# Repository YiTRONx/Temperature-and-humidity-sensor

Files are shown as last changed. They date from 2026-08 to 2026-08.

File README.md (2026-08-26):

# 温湿度传感器 Temperature-and-humidity-sensor
这是我的本科毕业设计，基于微信小程序的温湿度监测系统。主体基于esp32-s3 supermini，通过蓝牙或wifi连接微信小程序，实现温湿度的远程查询、阈值报警、历史数据查看等功能。
> Temperature and Humidity Monitoring System Based on WeChat Mini Program







基于 **ESP32-S3 + AHT10** 的物联网温湿度监测系统，以**微信小程序**作为上位机，通过**蓝牙**完成设备配网与本地参数配置，通过 **WiFi + MQTT** 实现远程数据上报与实时监测，配合 **Node-RED + Mosquitto** 服务器完成数据持久化、历史查询与微信报警推送。

低成本、高集成、易部署的远程温湿度监测解决方案，适用于农业大棚、仓储库房、机房、智能家居等场景。

**部分关于项目的图片可以查看仓库中的“基于微信小程序的温湿度监测系统.pdf”文件**

---

## 项目简介 / Introduction

传统温湿度监测方式存在布线复杂、交互性差、专用客户端适配繁琐等问题，难以满足远程智能监测需求。本项目打造一套完整闭环的物联网监测系统，采用**硬件采集层 → 无线通信层 → 服务器层 → 小程序应用层**的四层架构，覆盖"采集 — 传输 — 存储 — 交互"全链路：

- **硬件采集层**：以 ESP32-S3 为主控，搭配 AHT10 高精度温湿度传感器与 OLED 显示屏，完成数据采集与本地可视化；
- **无线通信层**：蓝牙负责近场配置（配网、参数下发），WiFi 负责远程数据传输（MQTT 上报）；
- **服务器层**：部署 Mosquitto 消息代理与 Node-RED 数据处理流，实现数据持久化、历史查询接口与微信通知推送，并通过内网穿透提供公网访问；
- **应用层**：微信小程序提供设备管理、实时监测、参数设置、历史数据查询等可视化交互。

## 功能特性 / Features

- 📊 **实时监测**：ESP32 双核并行采集，数据经 MQTT 实时上报，小程序同步展示温湿度数值与动态曲线
- 📡 **双模通信**：蓝牙 BLE（近场配置与数据传输）+ WiFi（远程上报与服务器通信）
- 🔧 **蓝牙配网**：无需将 WiFi 账号密码写死在固件中，小程序内直接下发 SSID / 密码完成入网
- 🚨 **阈值报警**：温度、湿度上下限均可配置，超限即时上报，服务器向用户微信推送报警通知
- 🗂️ **历史数据**：服务端按日持久化为 CSV 文件，小程序按日期查询并绘制历史曲线
- 🔗 **多设备管理**：蓝牙扫描绑定、多设备列表、断线自动重连
- 🖥️ **本地可视化**：0.96 寸 OLED 实时显示温湿度、通信状态与阈值信息
- 💾 **参数持久化**：全部配置写入 Flash（Preferences），掉电复位不丢失
- 🔋 **低功耗设计**：联网成功后自动关闭蓝牙，触摸唤醒 + 定时熄屏

## 系统架构 / Architecture

```
┌────────────────────────────────────────────────────────────────┐
│                    微信小程序（应用层）                             │
│   设备总览 · 实时监测 · 参数设置 · 历史数据 · 个人中心                   │
└───────────┬──────────────────────────────────┬──────────────────┘
            │ MQTT over WebSocket              │ HTTP
            │ 实时数据订阅                        │ 历史 CSV 查询
┌───────────▼──────────────────────────────────▼──────────────────┐
│           服务器层（Mosquitto + Node-RED）                         │
│   数据接收转发 · CSV 持久化 · HTTP 查询接口 · 微信报警通知              │
└───────────┬─────────────────────────────────────────────────────┘
            │ MQTT over TCP
┌───────────▼─────────────────────────────────────────────────────┐
│        无线通信层（ESP32 双模）                                     │
│   蓝牙 BLE（近场配置 / 指令下发）   WiFi（远程数据上传）                 │
└───────────┬─────────────────────────────────────────────────────┘
            │ I2C
┌───────────▼─────────────────────────────────────────────────────┐
│        硬件采集层（ESP32-S3 + AHT10 + OLED + 触摸开关）              │
└─────────────────────────────────────────────────────────────────┘
```

```mermaid
graph LR
    A[AHT10 温湿度传感器] -->|I2C| B[ESP32-S3]
    C[SSD1315 OLED] -->|I2C| B
    D[TTP223 触摸开关] -->|GPIO| B
    B -->|BLE| E[微信小程序]
    B -->|WiFi / MQTT| F[Mosquitto 消息代理]
    F --> G[Node-RED 数据处理流]
    G --> H[CSV 历史数据]
    G --> I[微信报警通知]
    E -->|MQTT / HTTP| F
```

核心数据链路：硬件采集温湿度 → WiFi / MQTT 上传至服务器存储 → 小程序通过 MQTT 获取实时数据、通过 HTTP 查询历史数据 → 小程序指令经蓝牙下发至硬件，实现双向交互。

## 技术栈 / Tech Stack

| 层级 | 技术 |
| --- | --- |
| 硬件 | ESP32-S3 Supermini、AHT10、SSD1315 OLED、TTP223 触摸开关 |
| 固件 | Arduino C、ESP32 双核任务调度、BLE、PubSubClient、Preferences |
| 服务器 | Mosquitto（MQTT Broker）、Node-RED、CSV、内网穿透 |
| 客户端 | 微信小程序原生开发（WebSocket 手写 MQTT 3.1.1 报文、Canvas 图表） |

## 目录结构 / Project Structure

```
Temperature-and-humidity-sensor
├── main_BLE_WiFi_MQTT_DualCore_NoEEPROM_Set.ino   # ESP32-S3 固件（Arduino）
└── wxamp_main/                                    # 微信小程序
    ├── app.js / app.json / app.wxss                # 全局逻辑、页面与样式配置
    ├── pages/
    │   ├── equipment/                              # 设备总览（蓝牙扫描 / 连接）
    │   ├── detailed/                               # 实时监测详情（数值 + 动态曲线）
    │   ├── detailed/detaileddaily/                 # 历史数据查询
    │   ├── setpage/                                # 参数设置入口
    │   │   ├── equwifi/                            # WiFi 配网
    │   │   ├── equalarm/                           # 温湿度告警阈值
    │   │   ├── equnickname/                        # 设备昵称
    │   │   ├── equdetailed/                        # 设备详情
    │   │   ├── equadd/                             # 添加设备
    │   │   └── otherset/                           # 其他设置
    │   ├── my/                                     # 个人中心（含通知、通用、帮助）
    │   ├── login/                                  # 用户登录
    │   └── canvasfortime/                          # 图表绘制
    ├── icons/                                      # 界面图标资源
    ├── utils/                                      # 工具函数（MQTT 封装、格式化等）
    └── date-csv/                                   # 历史数据文件示例
```

## 硬件设计 / Hardware Design

系统以**高集成度、低功耗、易调试**为选型原则，采用模块化连接设计，通过 SH1.0 接口实现各外设与主控的可靠对接，并由主控板提供 3.3V 供电。

### 硬件清单

| 模块 | 型号 | 说明 |
| --- | --- | --- |
| 主控 | ESP32-S3 Supermini | WiFi + BLE 双模、双核 240MHz，Type-C 供电与程序烧录 |
| 温湿度传感器 | AHT10 | I2C 通信，温度 -40~85℃（±0.3℃），湿度 0~100%RH（±2%RH），宽电压 1.8~6.0V |
| 显示屏 | SSD1315 0.96" OLED | I2C 128×64，本地数据与状态可视化 |
| 触摸开关 | TTP223 | 低电平触发屏幕唤醒，降低功耗 |
| 外壳 | 3D 打印（上下卡扣式） | 一体化成品，提升防护与质感 |
| PCB | 嘉立创 EDA 定制 | 紧凑化、模块化、易装配，SH1.0 贴片接口 |

### 引脚连接

| 外设 | 引脚 / 地址 | 说明 |
| --- | --- | --- |
| I2C SDA | GPIO8 | AHT10 与 OLED 共用 |
| I2C SCL | GPIO9 | AHT10 与 OLED 共用 |
| AHT10 | I2C 地址 `0x38` | 温湿度采集 |
| OLED | I2C 地址 `0x3C` | 本地显示 |
| 触摸开关 | GPIO13 | 屏幕唤醒触发 |

### 固件默认配置

| 配置项 | 默认值 |
| --- | --- |
| 设备广播名 | `ESP32-TH-V2` |
| 默认设备昵称 | `温湿度传感器V2.1` |
| 温度告警阈值 | 0 ~ 30℃ |
| 湿度告警阈值 | 0 ~ 80%RH |
| 采样 / 上报间隔 | 2000 ms |
| 熄屏时间 | 0（常亮） |
| NTP 服务器 | `ntp.aliyun.com`（UTC+8） |

## 通信协议 / Communication Protocols

### MQTT 主题

| 主题 | 方向 | 说明 |
| --- | --- | --- |
| `home/sensor/th` | 设备 → 服务器 | 实时温湿度数据上报 |
| `home/alarm/th` | 设备 → 服务器 | 阈值报警消息 |
| `device/online` | 设备 → 服务器 | 设备上线状态 |

实时数据上报格式（JSON）：

```json
{
  "time": "2026-03-15 10:00:00",
  "UUID": "<设备唯一标识>",
  "Nickname": "客厅传感器",
  "Location": "客厅",
  "temp": 25.3,
  "humi": 45.6
}
```

小程序端通过 WebSocket 连接 MQTT Broker（如 `ws://<服务器地址>:<端口>/mqtt`），手写 MQTT 3.1.1 报文完成连接与主题订阅，无需第三方库，并支持断线退避重连。

### 蓝牙 BLE

- **服务 UUID / 特征 UUID**：定义于固件头部（`SERVICE_UUID` / `CHARACTERISTIC_UUID`），小程序按服务 UUID 前缀匹配
- **特征属性**：READ + WRITE + NOTIFY + INDICATE，MTU 512
- **实时数据广播格式**：`温度,湿度`（如 `25.3,45.6`）

### 蓝牙指令集

| 指令 | 功能 | 回复 |
| --- | --- | --- |
| `WIFI:<ssid>,<password>` | 下发 WiFi 配网信息 | `WIFI_OK` / `WIFI_FORMAT_ERR` |
| `TEMP:<lower>,<upper>` | 设置温度告警阈值 | `TEMP_OK:<lower>,<upper>` |
| `HUM:<lower>,<upper>` | 设置湿度告警阈值 | `HUM_OK:<lower>,<upper>` |
| `NICK:<名称>` | 设置设备昵称（UTF-8） | `NICK_OK` / `NICK_FAIL` |
| `LOC:<位置>` | 设置安装位置 | `LOC_OK` / `LOC_FAIL` |
| `MQTT:<server>,<port>` | 设置 MQTT 服务器 | `MQTT_OK` / `MQTT_FAIL` |
| `REFRESH:<ms>` | 设置采样 / 上报间隔（500~30000 ms） | `REFRESH_OK` / `REFRESH_FAIL` |
| `SCREEN:<ms>` | 设置熄屏时间（0=常亮） | `SCREEN_OK` |
| `GET_CONFIG` | 读取全部配置 | `TEMP|HUM|NICK|LOC|MQTT|REFRESH|SCREEN` |
| `CLEAR` | 清除全部配置并恢复默认 | `CLEAR_OK` |

### HTTP 历史数据接口

```
GET /<设备UUID>/<YYYY-MM-DD>.csv
```

服务端返回按 `日期 时间 温度 湿度` 排列的 CSV 文件，小程序本地解析并绘制历史曲线。

## 快速开始 / Quick Start

### 1. 烧录固件（ESP32-S3）

1. 安装 Arduino IDE（或 PlatformIO），并安装 ESP32 开发板支持包；
2. 安装依赖库：`U8g2lib`、ESP32 BLE 库、`PubSubClient`、`Preferences`；
3. 按需修改固件头部配置：MQTT 服务器地址与端口、NTP 服务器（默认 `ntp.aliyun.com`，时区 UTC+8）等，也可通过小程序蓝牙指令动态下发；
4. 使用 Type-C 连接开发板，选择对应串口编译烧录。

### 2. 搭建服务器（远程监测依赖）

1. 部署 **Mosquitto** MQTT 消息代理，开放 TCP 端口（设备上报）与 WebSocket 端口（小程序订阅）；
2. 导入 **Node-RED** 数据处理流，包含四条核心流程：
   - 订阅 MQTT 设备主题 → 按 `<UUID>/<日期>.csv` 规则持久化存储；
   - HTTP GET 查询接口 → 读取并返回历史 CSV 文件；
   - 用户登录 → 获取并存储微信 OpenID；
   - 报警主题 → 触发微信通知推送；
3. 使用内网穿透工具（如 cpolar）将 MQTT、Node-RED 等端口映射到公网，实现设备与小程序跨网络稳定通信。

### 3. 运行微信小程序

1. 使用微信开发者工具导入 `wxamp_main` 目录；
2. 填入小程序 AppID，并配置以下服务器地址：
   - MQTT over WebSocket 地址（如 `ws://<服务器地址>:<端口>/mqtt`）；
   - HTTP 历史数据接口地址；
3. 编译预览。蓝牙扫描、配网等功能需在真机上测试。

## 使用指南 / Usage Guide

1. **添加设备**：设备总览页点击"+"，扫描并绑定附近的温湿度传感器；
2. **蓝牙配网**：进入设置页 WiFi 选项，下发 WiFi 名称与密码，设备自动联网并连接 MQTT 服务器；
3. **实时监测**：详情页以数值与动态曲线双形式展示温湿度，更新频率与设备采样周期一致；
4. **参数配置**：通过蓝牙可调整告警阈值、设备昵称、安装位置、采样间隔、熄屏时间等；
5. **历史查询**：历史数据页选择日期，小程序请求 CSV 并绘制当日温湿度曲线；
6. **阈值报警**：数据越限后设备上报报警消息，服务器向用户微信推送通知；
7. **登录授权**：个人中心支持头像、昵称设置与微信通知授权。

## 技术亮点 / Highlights

- **双核任务调度**：核心 1 独立完成 NTP 时间同步与 MQTT 连接，避免网络阻塞核心 0 的采集与显示流程；
- **原生 WebSocket 实现 MQTT**：小程序端手写 MQTT 3.1.1 报文（CONNECT / SUBSCRIBE / PUBLISH 解析），零第三方依赖，支持断线退避重连；
- **动态配网**：WiFi 凭证经蓝牙下发，账号密码不再写死在固件中；
- **参数持久化**：基于 Preferences（NVS Flash）替代 EEPROM，断电复位后配置不丢失；
- **省电策略**：WiFi 与服务器连接成功后自动关闭蓝牙；触摸唤醒 + 定时熄屏；
- **成品化落地**：定制 PCB + 3D 打印外壳，完成从模块化调试到一体化成品的全流程。

## 测试与验证 / Testing

- **功能测试**：蓝牙扫描 / 绑定、WiFi 配网、MQTT 实时数据、参数下发、历史查询、阈值报警推送均通过验证；
- **精度验证**：小程序显示数据与硬件 OLED 显示完全一致，采集误差满足传感器标称精度；
- **稳定性测试**：长时间运行无断连、死机、数据错乱，满足农业、仓储、家居等多场景监测需求。

## 应用场景 / Use Cases

- 🌱 农业大棚温湿度监测
- 📦 仓储库房环境监控
- 🖥️ 机房 / 设备间环境保障
- 🏠 智能家居环境感知
- 📷 摄影器材、贵重物品防潮监测

## 开源许可 / License

本项目仅供学习、毕业设计参考使用。

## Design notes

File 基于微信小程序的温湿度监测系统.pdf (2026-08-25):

目录

CONTENTS

## 项目设计说明

Project Design Description

## 硬件设计与服务器部署

## 测试与总结

## 微信小程序设计

WeChat Mini Program Design

Hardware Design and Server Deployment

Testing and summary

1
2
3

4

# 项目设计说明

Project Design Description

1

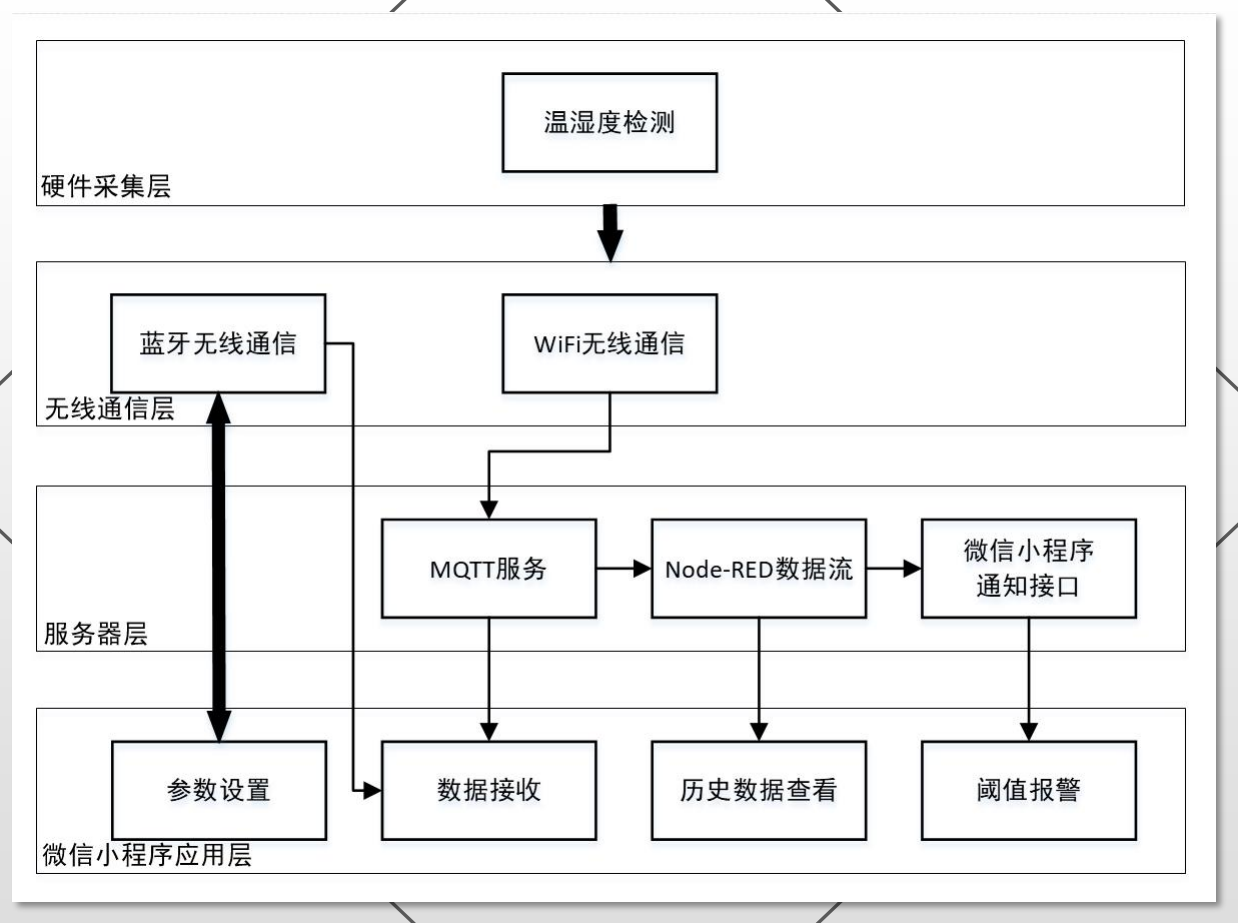
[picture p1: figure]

# 项目设计说明

Project Design Description

本项目设计基于微信小程序的温湿度监测
系统，采用硬件采集、无线通信、服务器、小
程序应用四层物联网架构。系统以ESP32-S3为
主控，搭配AHT10传感器与OLED屏，通过定制
PCB和3D打印外壳实现成品化，双核调度实现
稳定运行。

采用蓝牙、WiFi双通信模式，结合MQTT协
议与服务器，完成远程数据传输和存储、历史
查询及微信告警推送。微信小程序实现蓝牙配
网、实时监测、参数设置与数据可视化。系统
功能完整、操作便捷，适用于多场景智能监测。

WeChat Mini Program Design

# 微信小程序设计

2

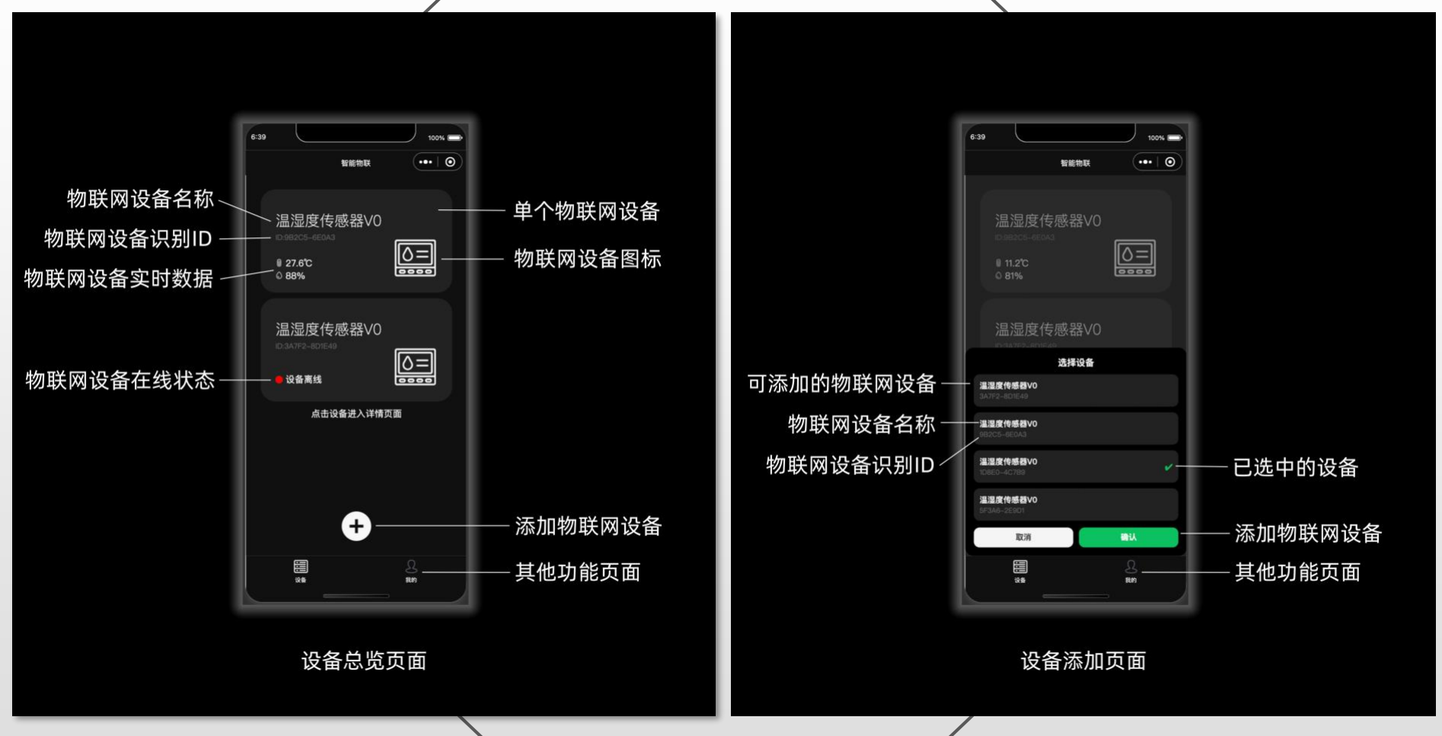
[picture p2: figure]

# 设备四大核心页面UI设计 ——设备总览页面

Page UI design

微信小程序的设备管理有四
大核心页面，分别为设备总览兼
添加页、设备详情页、参数设置

页、历史数据页。
设备总览兼连接页展示所有
已连接的设备和简单数据 ，并有
连接按键，点击弹出设备连接窗
口提供设备连接。

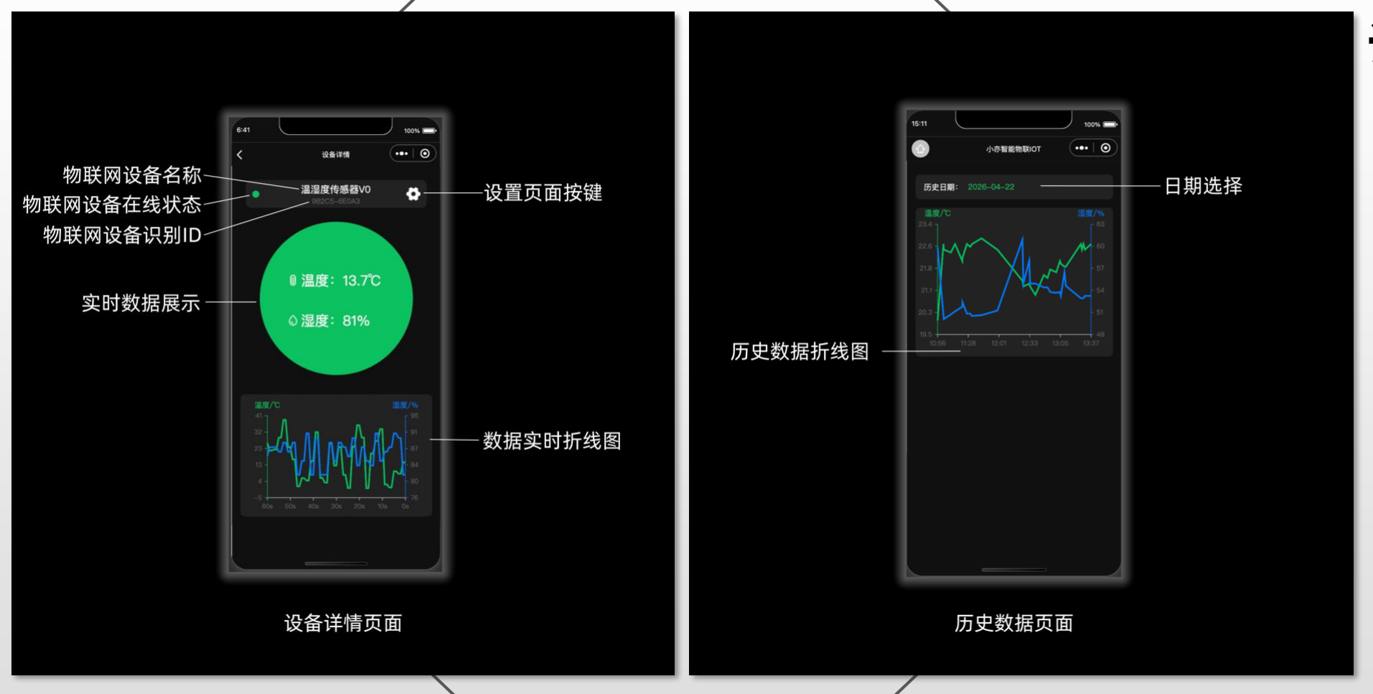
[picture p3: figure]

# 设备四大核心页面UI设计

——设备详细页面、历史数据页面

Page UI design

设备详情页面通过数值与简
易图形相结合的形式，直观展示
温湿度的实时读数和变化趋势。
历史数据页通过点击详细监
测页的图标进入，提供日期选择
器，用于历史数据查询，展示当
日所有数据绘制成的曲线图。

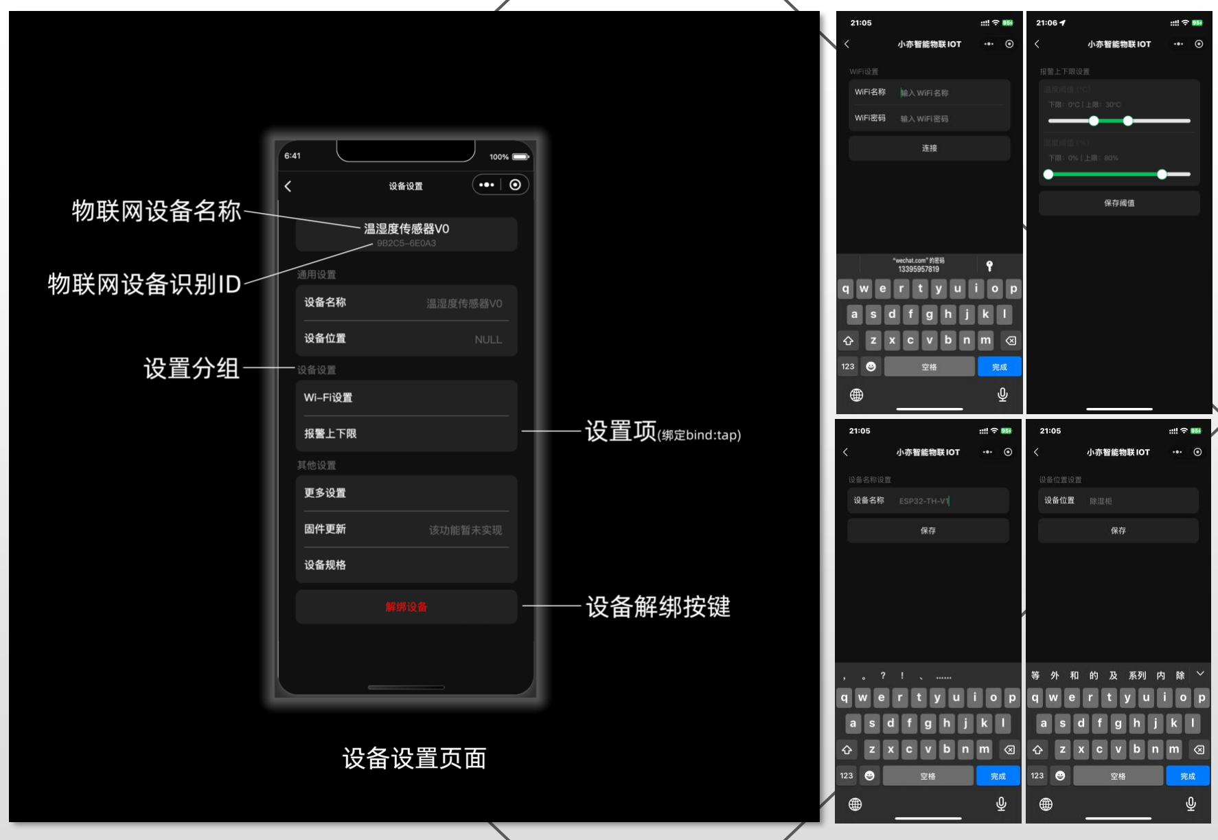
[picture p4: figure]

设备设置页面集成了对该设
备的WiFi入网信息、温湿度告警
阈值、设备别名及安装位置等多
类可调节选项，也为未来可能实
现的功能预留入口。
设备连接蓝牙后，可以进入
设置页面更该设备的可调节选项。

# 设备四大核心页面UI设计 ——设备设置页面

Page UI design

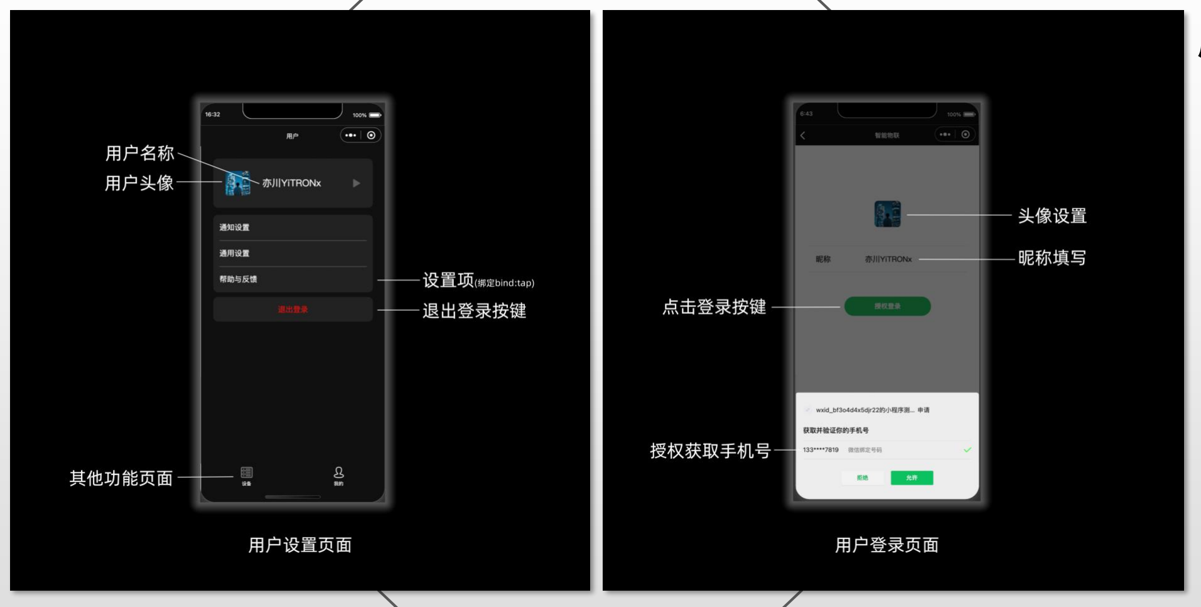
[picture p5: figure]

# 用户两大核心页面UI设计

Page UI design

用户两个核心页面分为用户
设置页面和用户登录页面，用户
登录页面为用户提供头像的设置、
昵称的填写，以及一个用来授权
登录的按键。
用户设置页面展示了用户设
置的头像和昵称，登录后用户就
能设置通知权限，是否允许服务
器向用户微信发送消息通知。

# 微信小程序代码工作逻辑

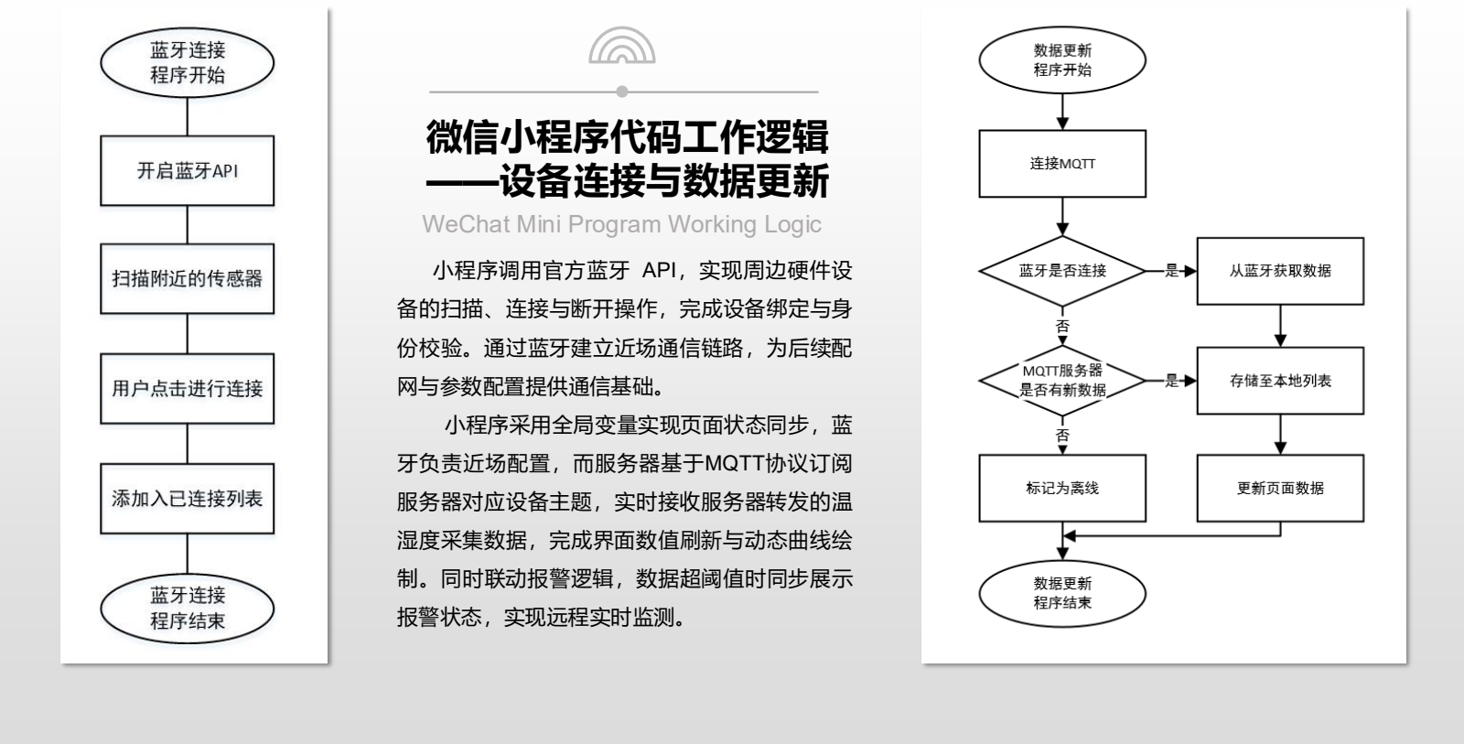
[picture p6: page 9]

# ——设备连接与数据更新

WeChat Mini Program Working Logic

小程序调用官方蓝牙 API，实现周边硬件设
备的扫描、连接与断开操作，完成设备绑定与身
份校验。通过蓝牙建立近场通信链路，为后续配
网与参数配置提供通信基础。
小程序采用全局变量实现页面状态同步，蓝
牙负责近场配置，而服务器基于MQTT协议订阅
服务器对应设备主题，实时接收服务器转发的温
湿度采集数据，完成界面数值刷新与动态曲线绘
制。同时联动报警逻辑，数据超阈值时同步展示
报警状态，实现远程实时监测。

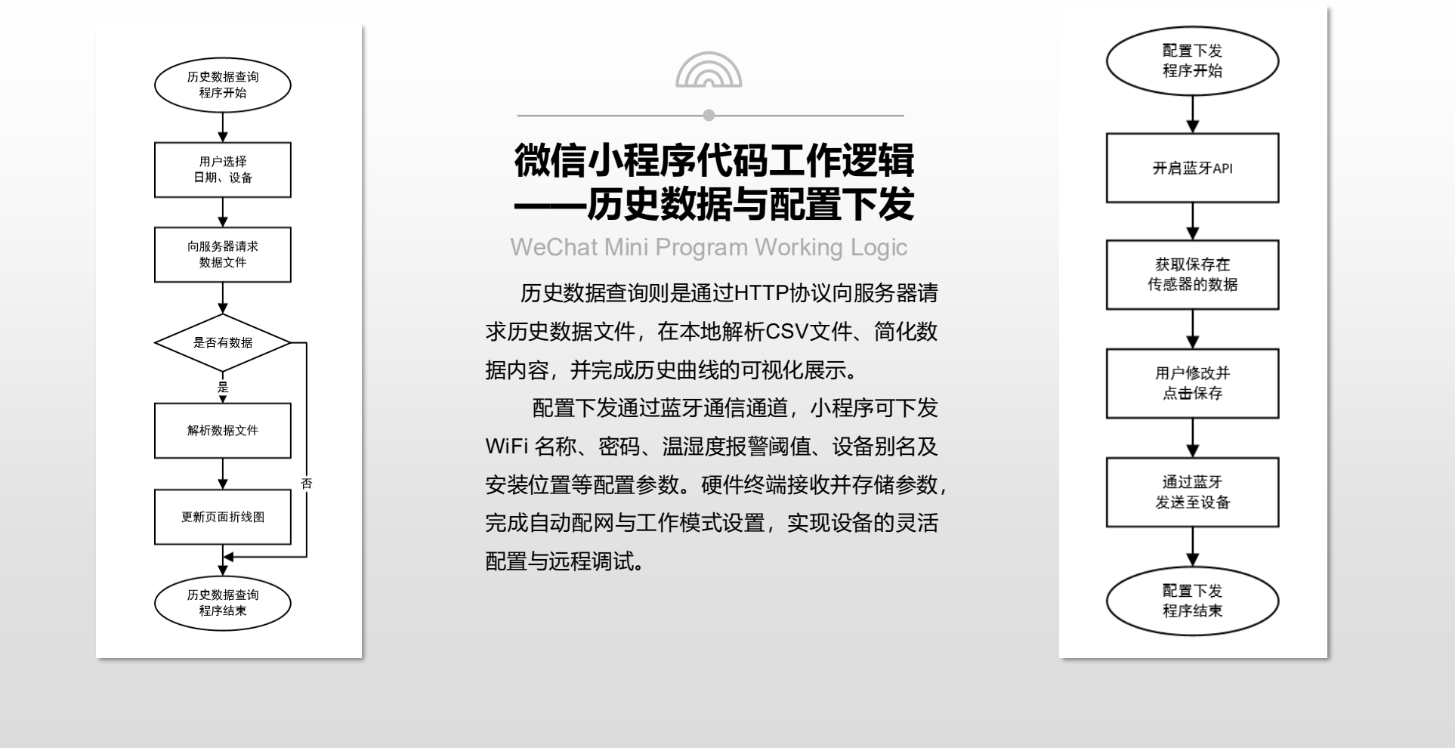
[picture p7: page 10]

# 微信小程序代码工作逻辑 ——历史数据与配置下发

WeChat Mini Program Working Logic

历史数据查询则是通过HTTP协议向服务器请
求历史数据文件，在本地解析CSV文件、简化数
据内容，并完成历史曲线的可视化展示。
配置下发通过蓝牙通信通道，小程序可下发
WiFi 名称、密码、温湿度报警阈值、设备别名及
安装位置等配置参数。硬件终端接收并存储参数，
完成自动配网与工作模式设置，实现设备的灵活
配置与远程调试。

Hardware Design and Server Deployment

# 硬件设计与服务器部署

3

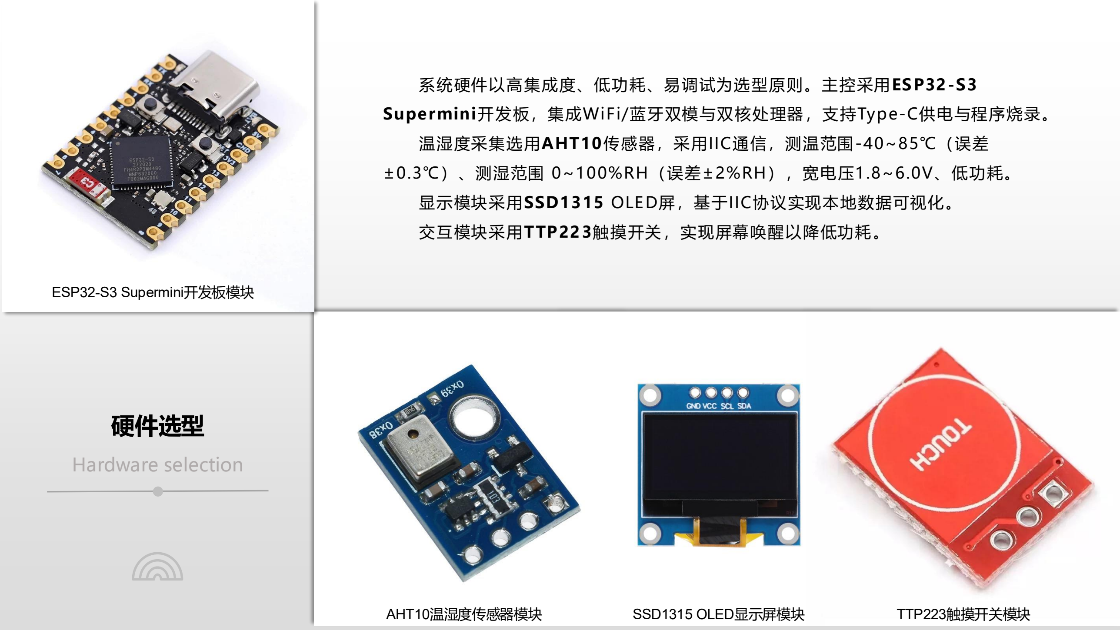
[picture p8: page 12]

Hardware selection

## 硬件选型

系统硬件以高集成度、低功耗、易调试为选型原则。主控采用ESP32-S3 Supermini开发板，集成WiFi/蓝牙双模与双核处理器，支持Type-C供电与程序烧录。 温湿度采集选用AHT10传感器，采用IIC通信，测温范围-40~85℃（误差 ±0.3℃）、测湿范围 0~100%RH（误差±2%RH），宽电压1.8~6.0V、低功耗。

显示模块采用SSD1315 OLED屏，基于IIC协议实现本地数据可视化。 交互模块采用TTP223触摸开关，实现屏幕唤醒以降低功耗。

ESP32-S3 Supermini开发板模块

AHT10温湿度传感器模块 | SSD1315 OLED显示屏模块 | TTP223触摸开关模块

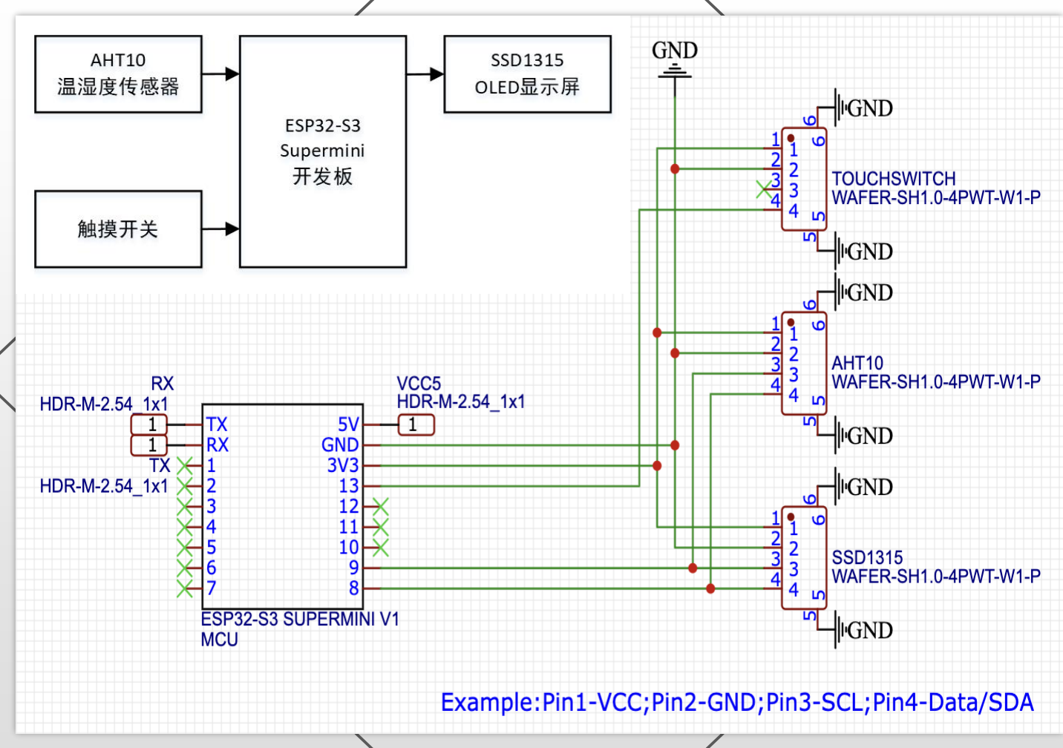
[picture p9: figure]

## 硬件电路连接

Hardware circuit connection

本系统电路以 ESP32-S3 Supermini 为 主控，采用模块化连接设计，通过 SH1.0接口
实现各外设与主控的可靠对接。AHT10温湿

度传感器与 SSD1315 OLED屏均基于IIC协议 通信，采用不同设备地址区分，共用主控

PIN8(SDA)、PIN9(SCL)引脚；触摸开关模块 接入主控 PIN13，实现低电平触发的屏幕唤醒
功能。各外设均由主控板提供 3.3V 电源。

# 硬件UI设计

Hardware UI design

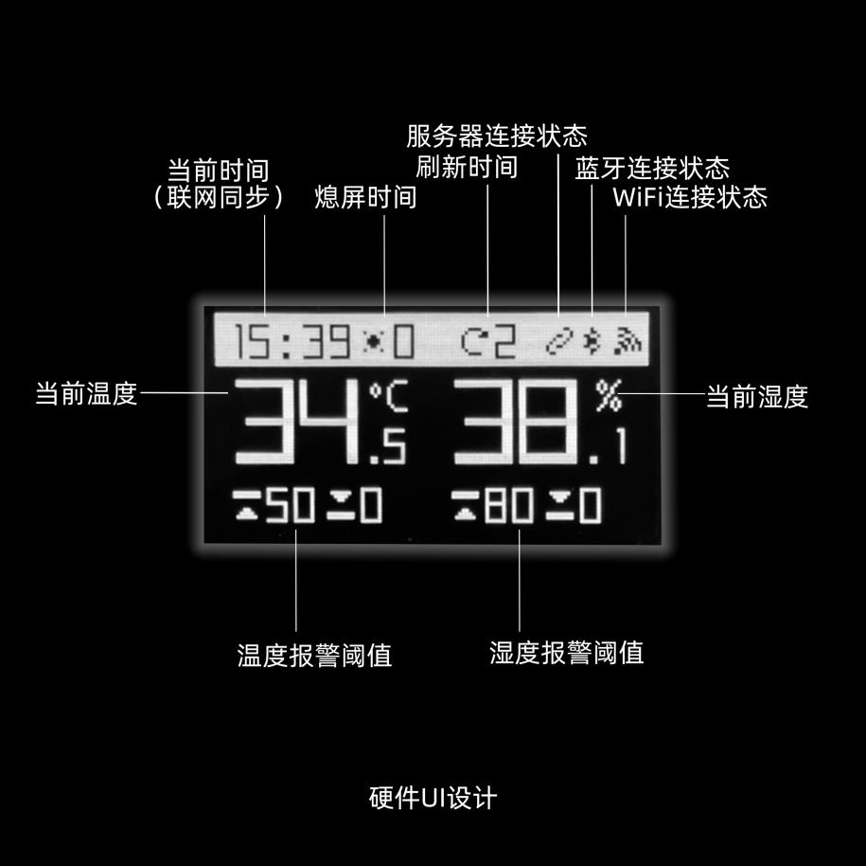
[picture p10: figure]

# 硬件代码工作逻辑

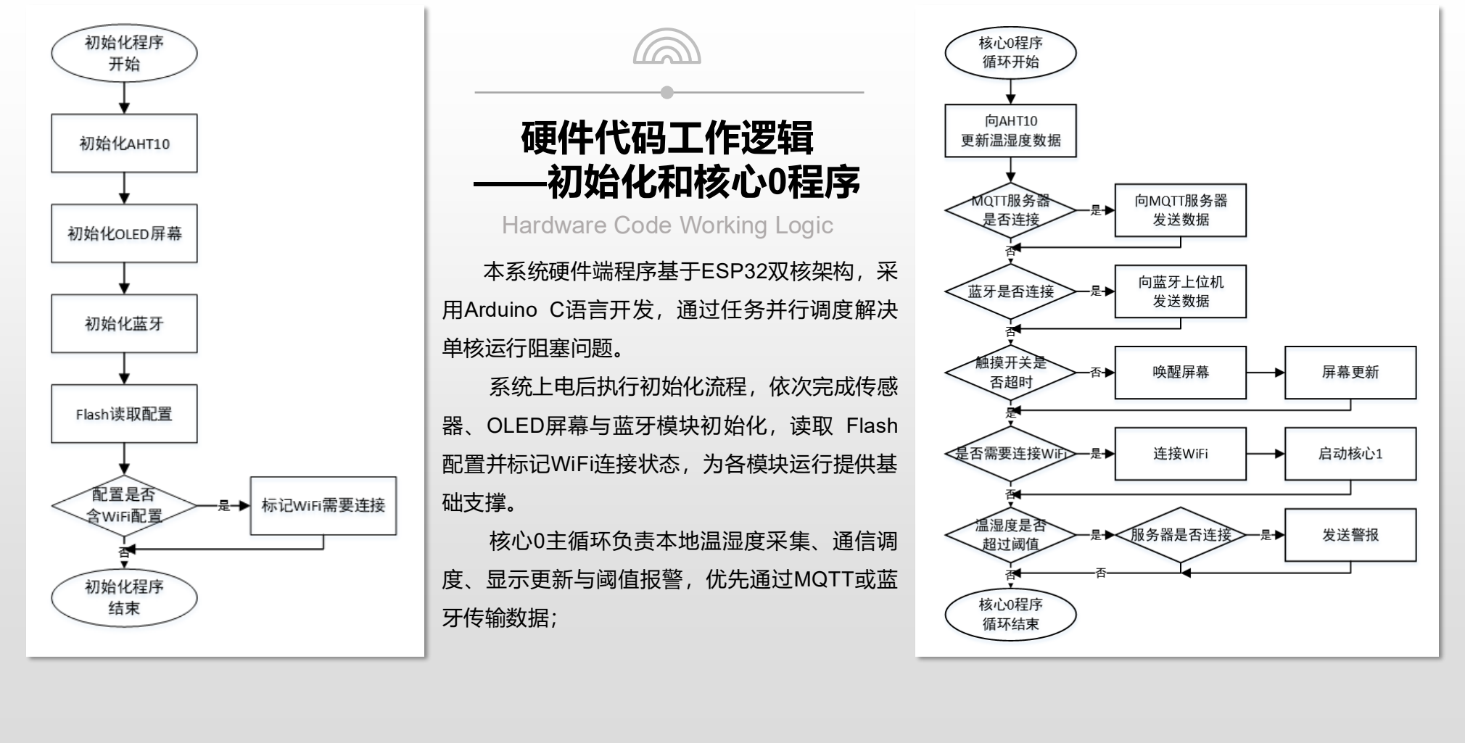
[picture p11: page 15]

# ——初始化和核心0程序

Hardware Code Working Logic

本系统硬件端程序基于ESP32双核架构，采
用Arduino C语言开发，通过任务并行调度解决
单核运行阻塞问题。
系统上电后执行初始化流程，依次完成传感

器、OLED屏幕与蓝牙模块初始化，读取 Flash
配置并标记WiFi连接状态，为各模块运行提供基
础支撑。
核心0主循环负责本地温湿度采集、通信调
度、显示更新与阈值报警，优先通过MQTT或蓝
牙传输数据；

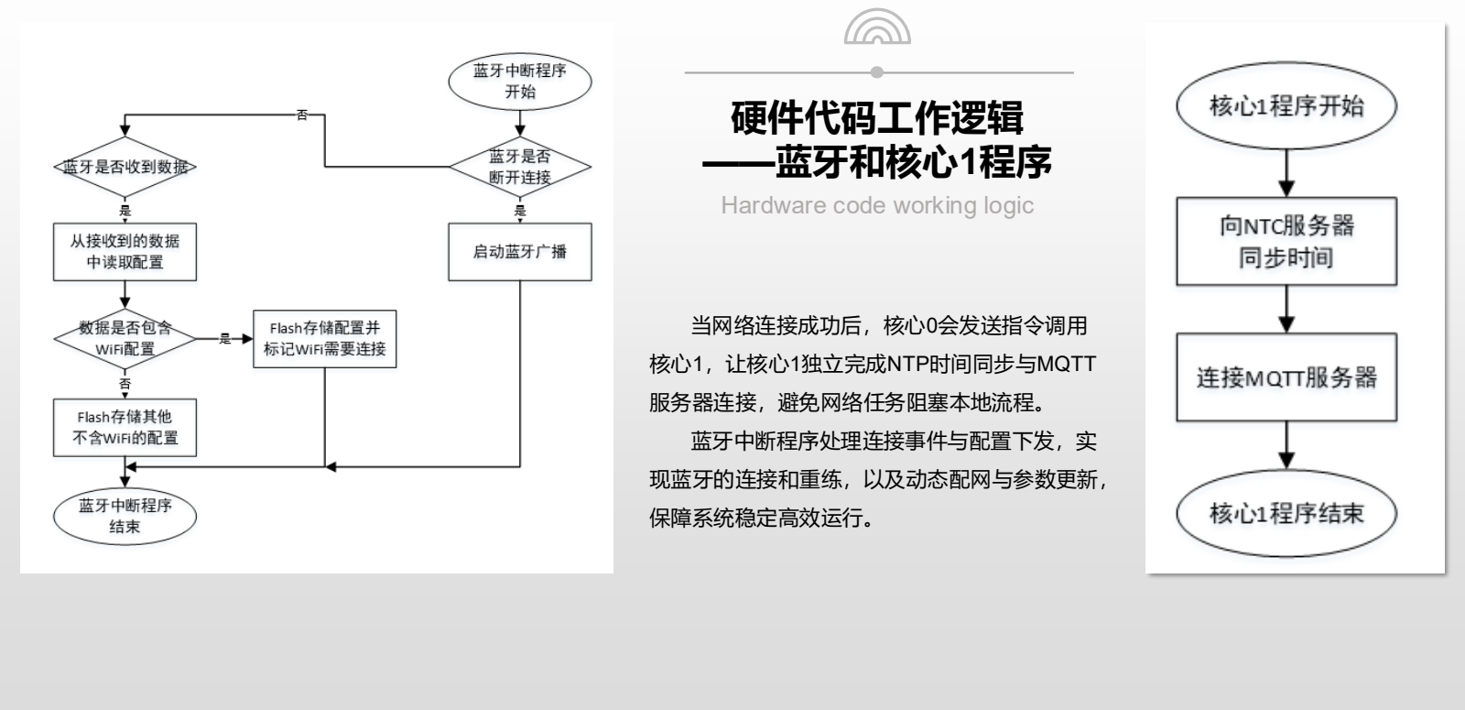
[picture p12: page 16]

# 硬件代码工作逻辑

## ——蓝牙和核心1程序

Hardware code working logic

当网络连接成功后，核心0会发送指令调用
核心1，让核心1独立完成NTP时间同步与MQTT
服务器连接，避免网络任务阻塞本地流程。
蓝牙中断程序处理连接事件与配置下发，实
现蓝牙的连接和重练，以及动态配网与参数更新，
保障系统稳定高效运行。

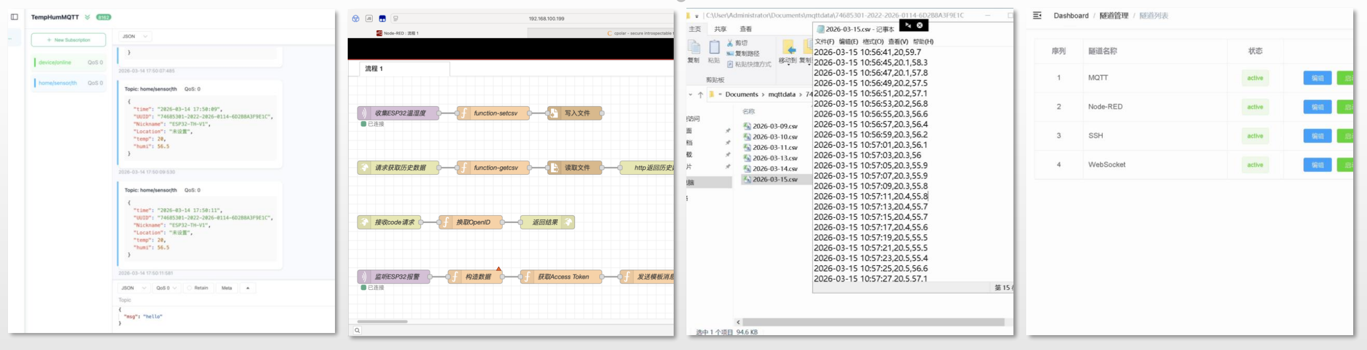
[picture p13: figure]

服务器核心功能依托MQTT协议与Node-RED平台构建。部署Mosquitto MQTT消息代理完成设备温湿度数据上报。

基于Node-RED搭建数据处理流，订阅MQTT设备主题并按/UUID/Date.csv规则将数据保存为CSV格式文件；开发 HTTP GET 查询接口，支 持按日期与设备UUID获取历史数据。系统存储用户数据并搭建通知发送流，实现温湿度阈值报警推送。通过内网穿透将本地服务映射为公网 URL，保障硬件设备与微信小程序跨网络稳定通信。

# 服务器部署

Server deployment

Testing and summary

# 测试与总结

4

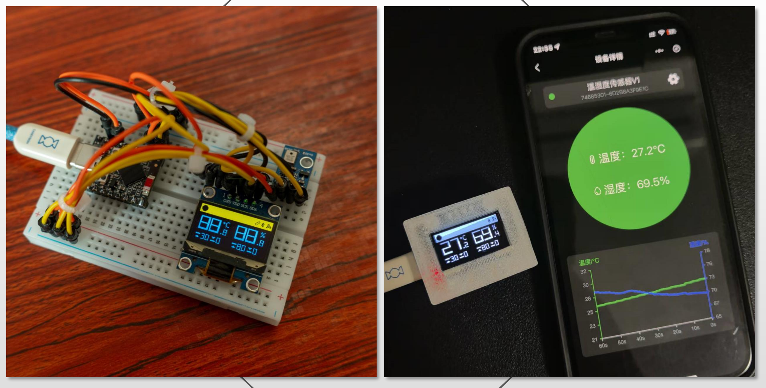
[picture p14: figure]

# 功能测试

Functional testing

经过测试，系统按要求达到预
期效果。微信小程序UI界面渲染流
畅，页面切换无卡顿，数据展示与
状态同步正常；硬件模块传感器、
显示屏通信正常，蓝牙与WiFi配网、
数据传输功能可靠；服务器MQTT
消息转发、CSV数据存储、HTTP
接口调用及内网穿透公网访问功能
均通过验证。

# 功能测试——连接和数据传输

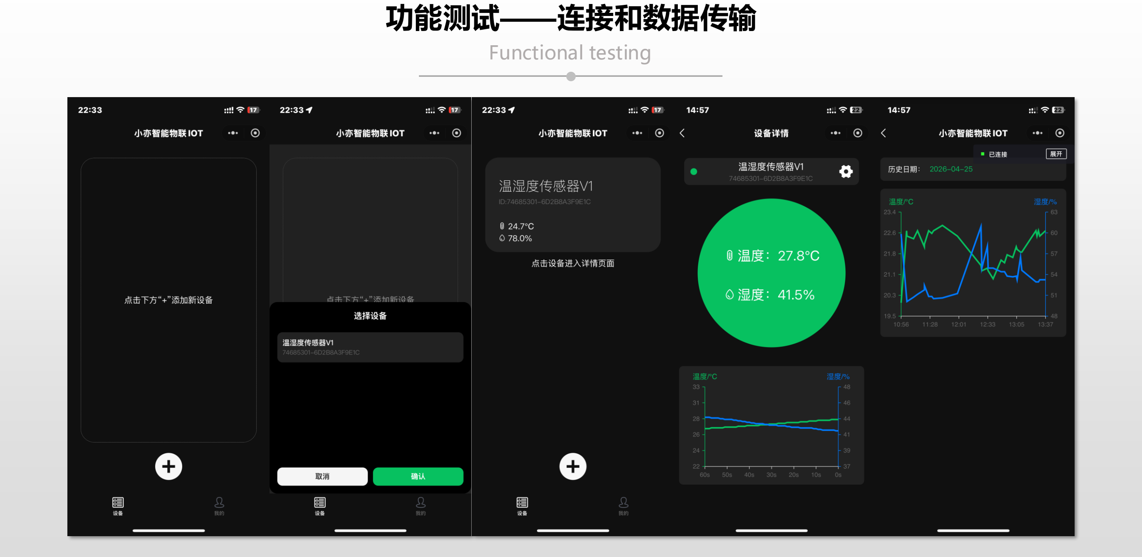
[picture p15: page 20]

Functional testing

# 功能测试——配置下发

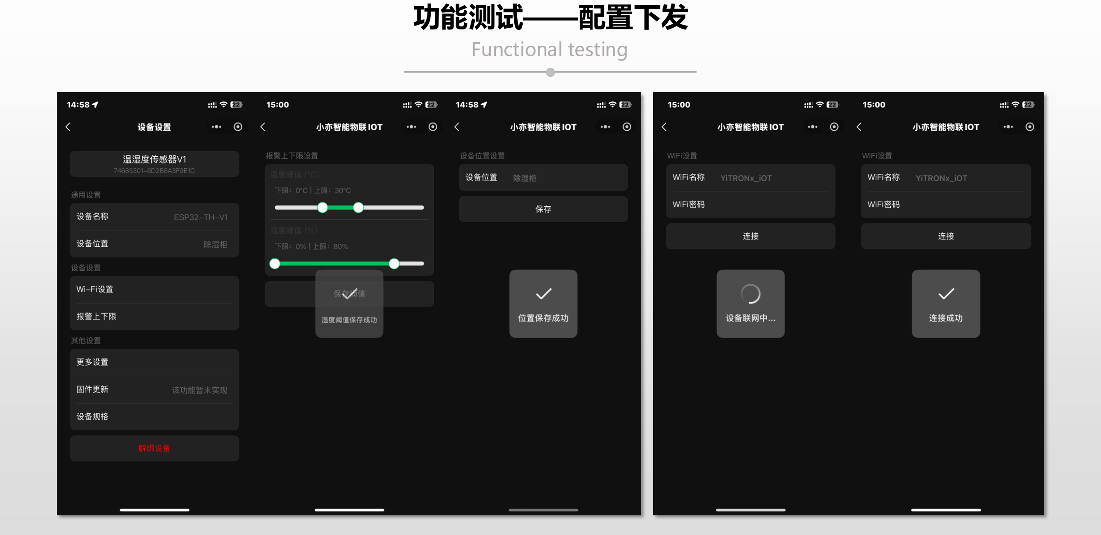
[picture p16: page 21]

Functional testing

# 功能测试——阈值报警

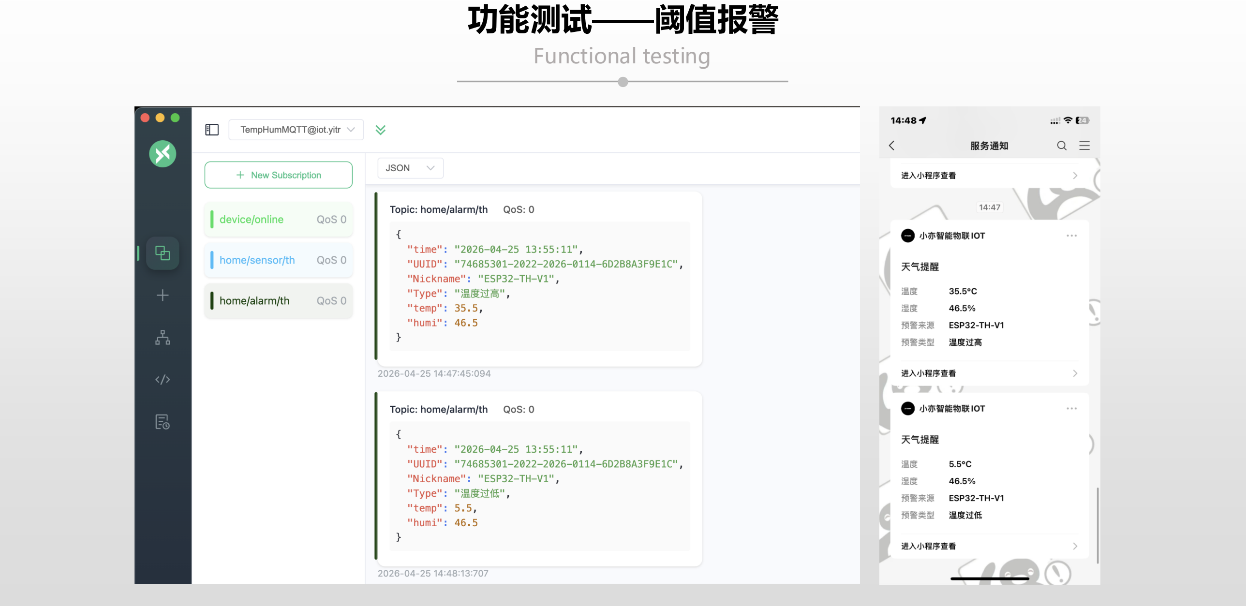
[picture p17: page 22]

Functional testing

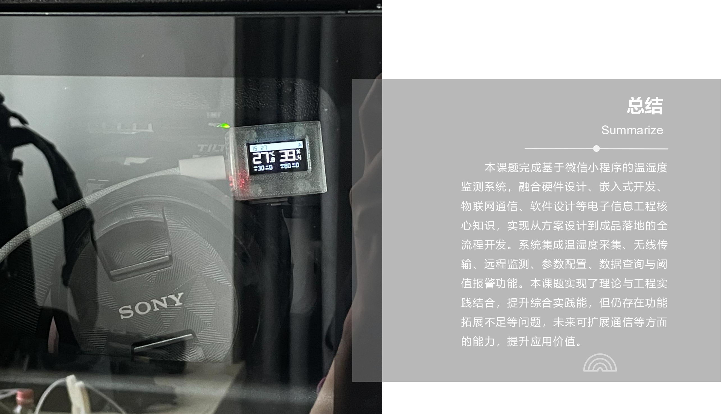
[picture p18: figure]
Summarize; 本课题完成基于微信小程序的温湿度; 监测系统，融合硬件设计、嵌入式开发、; 物联网通信、软件设计等电子信息工程核; 心知识，实现从方案设计到成品落地的全; 流程开发。系统集成温湿度采集、无线传; 输、远程监测、参数配置、数据查询与阈; 值报警功能。本课题实现了理论与工程实; 践结合，提升综合实践能，但仍存在功能; 拓展不足等问题，未来可扩展通信等方面; 的能力，提升应用价值。

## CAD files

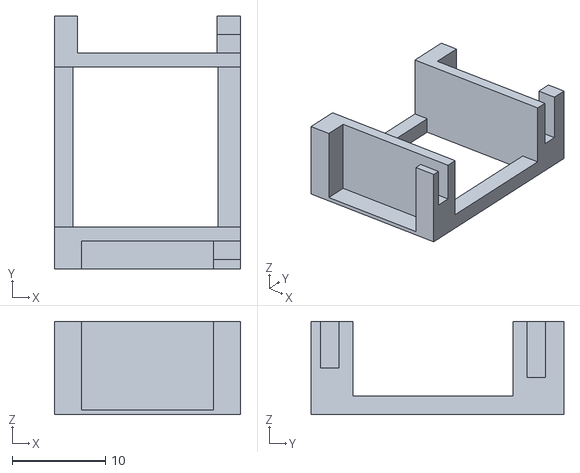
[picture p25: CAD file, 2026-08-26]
hardware/shell/内部支架.stl
20.0 x 27.2 x 10.0

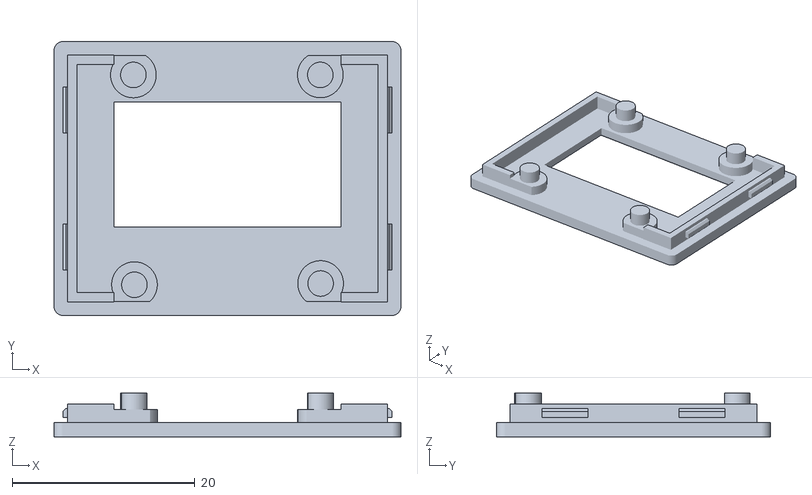
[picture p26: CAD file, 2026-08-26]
hardware/shell/上盖.stl
38.0 x 30.0 x 4.80

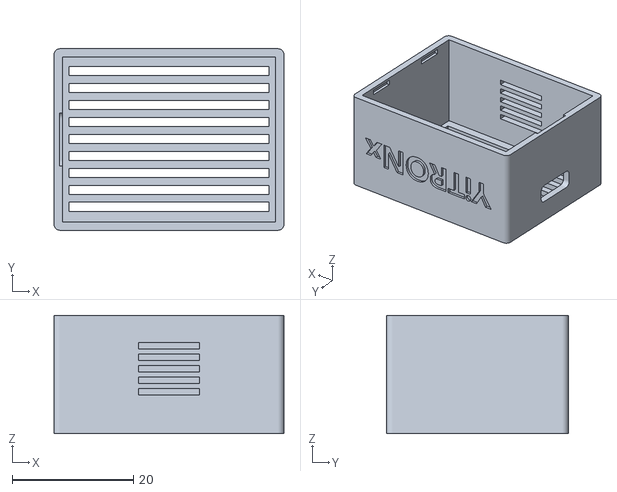
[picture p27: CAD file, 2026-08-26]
hardware/shell/外壳.stl
38.0 x 30.0 x 19.5

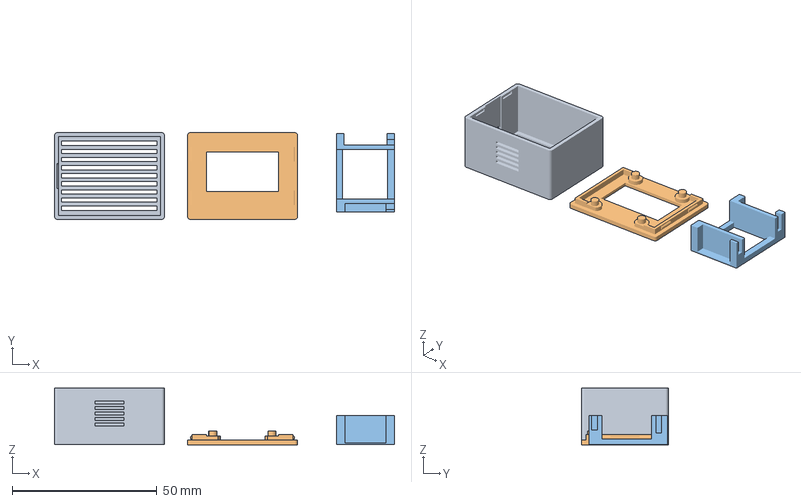
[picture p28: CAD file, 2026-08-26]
hardware/shell/3D打印文件.3mf
117.5 x 30.0 x 19.6 mm

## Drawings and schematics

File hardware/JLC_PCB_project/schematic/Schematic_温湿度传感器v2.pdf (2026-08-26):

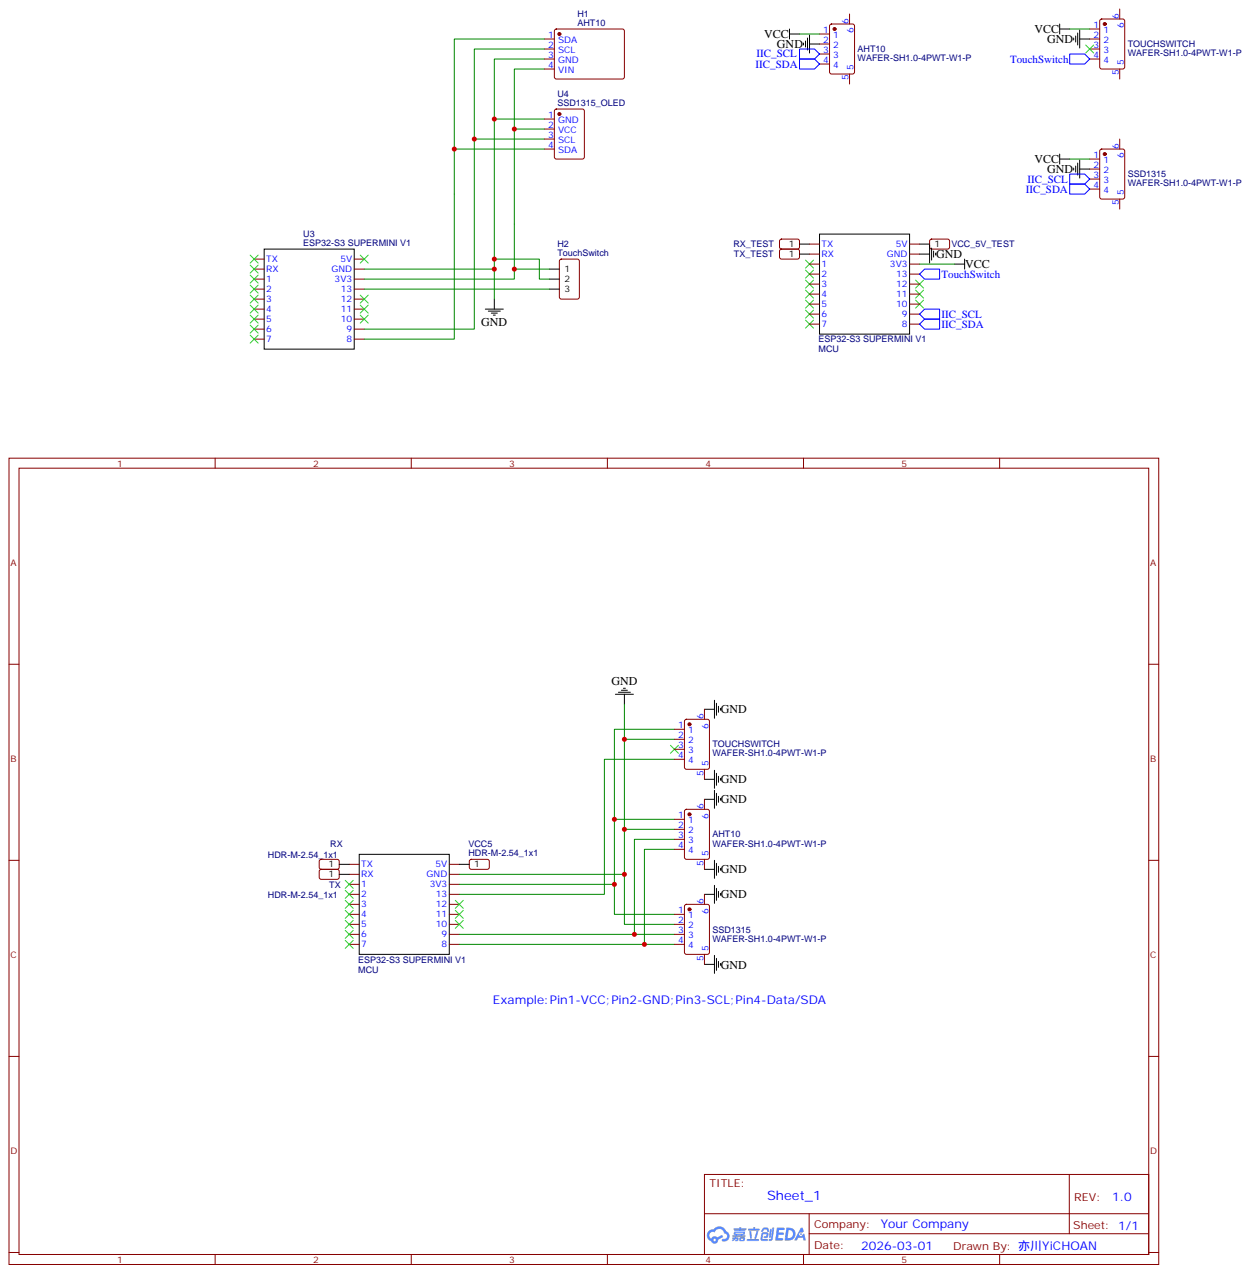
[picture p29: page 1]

Example:Pin1-VCC;Pin2-GND;Pin3-SCL;Pin4-Data/SDA

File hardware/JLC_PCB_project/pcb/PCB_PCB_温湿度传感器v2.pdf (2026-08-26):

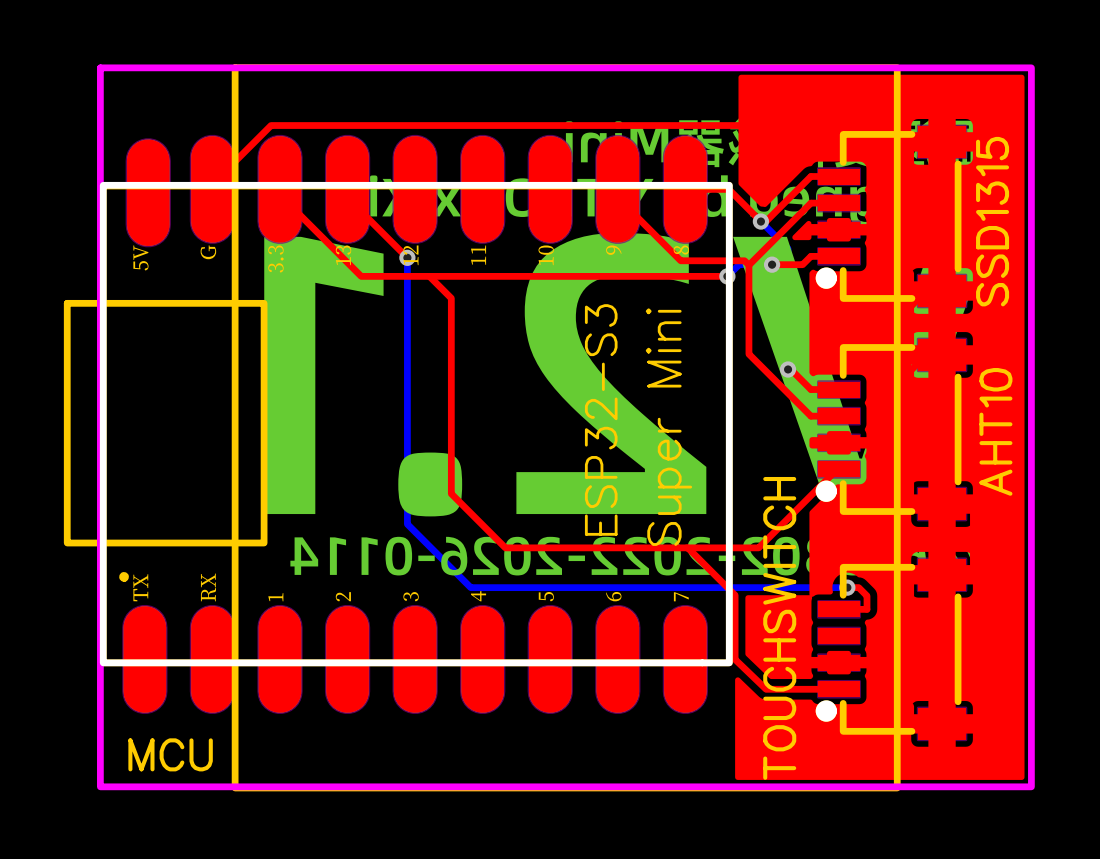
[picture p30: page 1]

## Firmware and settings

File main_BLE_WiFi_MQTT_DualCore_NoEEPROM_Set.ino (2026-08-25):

#include <Arduino.h>
#include <U8g2lib.h>
#include <Wire.h>
#include <BLEDevice.h>
#include <BLEServer.h>
#include <BLEUtils.h>
#include <BLE2902.h>
#include <WiFi.h>
#include <PubSubClient.h>
#include "time.h"
// 引入ESP32内置Flash存储库（替代EEPROM）
#include <Preferences.h>
#include<esp_system.h>

// --- AHT10 相关定义 ---
#define AHT10_ADDR 0x38
#define CMD_INIT 0xE1
#define CMD_MEASURE 0xAC

float temperature, humidity;    //存储读取结果
float temp_result, hum_result;  //结果保留一位小数
int temp_decimal=8,temp_integer=88;  //温度整数小数分离
int hum_decimal=8,hum_integer=88;    //湿度整数小数分离

// --- OLED 初始化（地址0x3C，保持原引脚配置） ---
U8G2_SSD1306_128X64_NONAME_F_HW_I2C u8g2(U8G2_R0, /* reset=*/ U8X8_PIN_NONE, /* clock=*/ 9, /* data=*/ 8);

// --- 配置结构体（替代原EEPROM配置，包含温湿度双阈值） ---
struct DeviceConfig {
  // WiFi配置（保持原结构）
  char ssid[32];
  char password[64];
  uint8_t hasConfig;
  
  // 温湿度阈值（同时包含温度+湿度）
  int TEMP_Upper;
  int TEMP_Lower;
  int HUM_Upper;
  int HUM_Lower;
  
  // 新增配置项
  char device_nickname[32];  // 设备昵称
  char device_location[64];  // 设备位置
  char mqtt_server[64];      // MQTT服务器地址
  uint16_t mqtt_port;        // MQTT端口
  unsigned long read_interval;  // 刷新频率(ms)
  unsigned long screen_off_time;// 熄屏时间(ms，0=常亮)
};

// 全局配置实例（初始化值保持原代码默认值）
DeviceConfig deviceConfig = {
  .ssid = "",
  .password = "",
  .hasConfig = 0,
  
  .TEMP_Upper = 30,
  .TEMP_Lower = 0,
  .HUM_Upper = 80,
  .HUM_Lower = 0,
  
  .device_nickname = "温湿度传感器V2.1",
  .device_location = "",
  .mqtt_server = "iot.yitronx.cn",
  .mqtt_port = 13343,
  .read_interval = 2000,
  .screen_off_time = 0
};

// --- Flash存储实例 ---
Preferences preferences;
#define CONFIG_NAMESPACE "TH_CONFIG"  // Flash命名空间

// --- WiFi 相关定义（完全保留原代码） ---
bool shouldConnectWiFi = false;
String pendingSSID = "";
String pendingPASS = "";
unsigned long wifiTimer = 0;
bool isConnecting = false;

// --- 蓝牙 相关定义（完全保留原代码） ---
#define SERVICE_UUID        "74685301-2022-2026-0114-6D2B8A3F9E1C"
// #define SERVICE_UUID        "74685301-2022-2026-0114-6D2B8A38AD4C"
#define CHARACTERISTIC_UUID "BEB5483E-36E1-4688-B7F5-EA07361B26A8"
#define DeviceName          "ESP32-TH-V2"
bool isAdvertising = false;//蓝牙闪烁用
bool bleRunning = false; //标记蓝牙当前运行状态
BLECharacteristic* pCharacteristic = NULL;
bool deviceConnected = false;

// --- 服务器 相关定义（完全保留原代码） ---
WiFiClient espClient;
PubSubClient client(espClient);
bool isServerConnected = false;
bool isServerConnecting = false;//闪烁用
portMUX_TYPE coreMux = portMUX_INITIALIZER_UNLOCKED;
volatile bool mqttReconnectFlag = false;
volatile bool timeSyncFlag = false;
volatile bool isTimeSynced = false;
volatile struct tm syncTimeInfo;

struct tm currentTime;
bool timeIsSynced = false;
bool mqttConnected = false;
bool bleDeviceConnected = false;

// --- 时间设置 相关定义（完全保留原代码） ---
const char* ntpServer = "ntp.aliyun.com";
const long  gmtOffset_sec = 28800;
const int   daylightOffset_sec = 0;

// --- 非阻塞定时器 相关定义 ---
unsigned long ReadTimer = 0;
unsigned long oledUpdateTimer = 0;
bool OLED_Flicker_Flag = true;
unsigned long mqttReconnectTimer = 0;
unsigned long lastMsg = 0;
const unsigned long READ_INTERVAL = 2000;
const unsigned long OLED_UPDATE_INTERVAL = 1000;
const unsigned long MQTT_RECONNECT_INTERVAL = 5000;
const unsigned long WiFi_Timeout_INTERVAL = 15000;

// --- 阈值报警功能 相关定义 ---
bool TEMP_Alarm_flag = false;
bool HUM_Alarm_flag = false;
unsigned long Alarm_Timer = 0;
int Display_Reversed = 1;
int MQTT_Alarm_temp = 0;//报警发送标志位
int MQTT_Alarm_hum = 0;//报警发送标志位

// --- 熄屏相关变量 ---
unsigned long screenOnTimer = 0;
bool screenIsOn = true;
#define TouchPin 13
int TouchState = 0;
int screenTime = 0;
int refreshTime = 0;

// ------------------------------
// Flash存储操作函数（替代原EEPROM函数）
// ------------------------------
// 保存配置到Flash
void saveConfigToFlash() {
  preferences.begin(CONFIG_NAMESPACE, false); // 可写模式
  
  // 保存WiFi配置（原EEPROM逻辑迁移）
  preferences.putBytes("wifi_ssid", deviceConfig.ssid, sizeof(deviceConfig.ssid));
  preferences.putBytes("wifi_pass", deviceConfig.password, sizeof(deviceConfig.password));
  preferences.putUChar("wifi_config", deviceConfig.hasConfig);
  
  // 保存温湿度阈值（核心：同时包含温度+湿度）
  preferences.putInt("temp_upper", deviceConfig.TEMP_Upper);
  preferences.putInt("temp_lower", deviceConfig.TEMP_Lower);
  preferences.putInt("hum_upper", deviceConfig.HUM_Upper);
  preferences.putInt("hum_lower", deviceConfig.HUM_Lower);
  
  // 保存新增配置项
  preferences.putBytes("nickname", deviceConfig.device_nickname, sizeof(deviceConfig.device_nickname));
  preferences.putBytes("location", deviceConfig.device_location, sizeof(deviceConfig.device_location));
  preferences.putBytes("mqtt_server", deviceConfig.mqtt_server, sizeof(deviceConfig.mqtt_server));
  preferences.putUShort("mqtt_port", deviceConfig.mqtt_port);
  preferences.putULong("read_interval", deviceConfig.read_interval);
  preferences.putULong("screen_off", deviceConfig.screen_off_time);
  
  preferences.end();
  Serial.println("配置已保存到Flash");
}

// 从Flash加载配置
void loadConfigFromFlash() {
  preferences.begin(CONFIG_NAMESPACE, true); // 只读模式
  
  // 加载WiFi配置（原EEPROM逻辑迁移）
  if (preferences.isKey("wifi_ssid")) {
    preferences.getBytes("wifi_ssid", deviceConfig.ssid, sizeof(deviceConfig.ssid));
    preferences.getBytes("wifi_pass", deviceConfig.password, sizeof(deviceConfig.password));
    deviceConfig.hasConfig = preferences.getUChar("wifi_config", 0);
  }
  
  // 加载温湿度阈值（核心：同时加载温度+湿度）
  deviceConfig.TEMP_Upper = preferences.getInt("temp_upper", 30);
  deviceConfig.TEMP_Lower = preferences.getInt("temp_lower", 0);
  deviceConfig.HUM_Upper = preferences.getInt("hum_upper", 80);
  deviceConfig.HUM_Lower = preferences.getInt("hum_lower", 0);
  
  // 加载新增配置项
  if (preferences.isKey("nickname")) {
    preferences.getBytes("nickname", deviceConfig.device_nickname, sizeof(deviceConfig.device_nickname));
  }
  if (preferences.isKey("location")) {
    preferences.getBytes("location", deviceConfig.device_location, sizeof(deviceConfig.device_location));
  }
  if (preferences.isKey("mqtt_server")) {
    preferences.getBytes("mqtt_server", deviceConfig.mqtt_server, sizeof(deviceConfig.mqtt_server));
  }
  deviceConfig.mqtt_port = preferences.getUShort("mqtt_port", 13343);
  deviceConfig.read_interval = preferences.getULong("read_interval", 2000);
  deviceConfig.screen_off_time = preferences.getULong("screen_off", 0);
  
  preferences.end();
  Serial.println("配置已从Flash加载");
  
  // 打印阈值（调试用，验证湿度阈值加载）
  Serial.printf("加载阈值：温度 %d~%d°C | 湿度 %d~%d%%\n", 
                deviceConfig.TEMP_Lower, deviceConfig.TEMP_Upper,
                deviceConfig.HUM_Lower, deviceConfig.HUM_Upper);
}

// 清除Flash中所有配置
void clearAllConfig() {
  preferences.begin(CONFIG_NAMESPACE, false);
  preferences.clear(); // 清空所有配置
  preferences.end();
  
  // 恢复默认配置（包含温湿度双阈值）
  memset(&deviceConfig, 0, sizeof(DeviceConfig));
  deviceConfig.TEMP_Upper = 30;
  deviceConfig.TEMP_Lower = 0;
  deviceConfig.HUM_Upper = 80;
  deviceConfig.HUM_Lower = 0;
  strcpy(deviceConfig.device_nickname, "温湿度传感器V2.1");
  strcpy(deviceConfig.device_location, "未设置");
  strcpy(deviceConfig.mqtt_server, "iot.yitronx.cn");
  deviceConfig.mqtt_port = 14167;
  deviceConfig.read_interval = 2000;
  deviceConfig.screen_off_time = 0;
  
  Serial.println("所有配置已清除，恢复默认值");
  ESP.restart();
}

// ------------------------------
// AHT10传感器（完全保留原代码）
// ------------------------------
bool initAHT10(){
  Wire.beginTransmission(AHT10_ADDR);
  Wire.write(CMD_INIT);
  Wire.write(0x08);  // 校准使能
  Wire.write(0x00);
  if (Wire.endTransmission() != 0) {
    return false;
  }
  delay(10);
  return true;
}

bool readAHT10(float &temp, float &humi) {
  uint8_t data[6] = {0};
  
  Wire.beginTransmission(AHT10_ADDR);
  Wire.write(CMD_MEASURE);
  Wire.write(0x33);
  Wire.write(0x00);
  if (Wire.endTransmission() != 0) {
    return false;
  }
  
  delay(80);
  
  Wire.requestFrom(AHT10_ADDR, 6);
  if (Wire.available() != 6) {
    return false;
  }
  
  for (int i = 0; i < 6; i++) {
    data[i] = Wire.read();
  }
  
  if (data[0] & 0x80) {
    return false;
  }
  
  uint32_t humi_raw = ((uint32_t)data[1] << 12) | 
                      ((uint32_t)data[2] << 4) | 
                      ((uint32_t)data[3] >> 4);
  humi = (float)humi_raw * 100.0 / 1048576.0;
  
  uint32_t temp_raw = (((uint32_t)data[3] & 0x0F) << 16) | 
                      ((uint32_t)data[4] << 8) | 
                      data[5];
  temp = (float)temp_raw * 200.0 / 1048576.0 - 50.0;
  
  return true;
}

// ------------------------------
// 蓝牙设置（核心修改：补充湿度阈值指令）
// ------------------------------
class MyServerCallbacks: public BLEServerCallbacks {
  void onConnect(BLEServer* pServer) {
    deviceConnected = true;
    isAdvertising = false;
    Serial.println("设备已连接");
    screenIsOn = true;
    screenOnTimer = millis();
  }
  void onDisconnect(BLEServer* pServer) {
    deviceConnected = false;
    isAdvertising = true;
    Serial.println("设备已断开，重新启动广播");
    BLEDevice::startAdvertising();
  }
};

class MyCallbacks: public BLECharacteristicCallbacks {
  void onWrite(BLECharacteristic *pC) {
    String rxValue = String(pC->getValue().c_str());
    rxValue.trim();
    Serial.print("收到蓝牙指令：");
    Serial.println(rxValue);
    screenIsOn = true;//收到指令唤醒屏幕
    screenOnTimer = millis();
    // 1. WiFi配置指令（完全保留原代码）
    if (rxValue.indexOf("WIFI:") == 0) {
      int commaIndex = rxValue.indexOf(',');
      if (commaIndex != -1) {
        pendingSSID = rxValue.substring(5, commaIndex);
        pendingPASS = rxValue.substring(commaIndex + 1);
        Serial.print("WiFi配置：ssid=");
        Serial.print(pendingSSID);
        Serial.print(", pass=");
        Serial.println(pendingPASS);
        
        pendingSSID.toCharArray(deviceConfig.ssid, sizeof(deviceConfig.ssid));
        pendingPASS.toCharArray(deviceConfig.password, sizeof(deviceConfig.password));
        deviceConfig.hasConfig = 0xAA;
        saveConfigToFlash();
        
        shouldConnectWiFi = true;
        pCharacteristic->setValue("WIFI_PROCESSING");
        pCharacteristic->notify();
      } else {
        pCharacteristic->setValue("WIFI_FORMAT_ERR");
        pCharacteristic->notify();
      }
    }
    // 2. 温度阈值指令
    else if (rxValue.indexOf("TEMP:") == 0) {
      int commaIndex = rxValue.indexOf(',');
      if (commaIndex != -1) {
        int upper = rxValue.substring(5, commaIndex).toInt();
        int lower = rxValue.substring(commaIndex + 1).toInt();
        deviceConfig.TEMP_Upper = upper;
        deviceConfig.TEMP_Lower = lower;
        saveConfigToFlash();
        
        Serial.printf("温度阈值已设置：%d~%d°C\n", lower, upper);
        pCharacteristic->setValue(String("TEMP_OK:") + lower + "," + upper);
        pCharacteristic->notify();
      } else {
        pCharacteristic->setValue("TEMP_FORMAT_ERR");
        pCharacteristic->notify();
      }
    }
    // 3. 湿度阈值指令
    else if (rxValue.indexOf("HUM:") == 0) {
      int commaIndex = rxValue.indexOf(',');
      if (commaIndex != -1) {
        int upper = rxValue.substring(4, commaIndex).toInt();
        int lower = rxValue.substring(commaIndex + 1).toInt();
        deviceConfig.HUM_Upper = upper;
        deviceConfig.HUM_Lower = lower;
        saveConfigToFlash();
        
        Serial.printf("湿度阈值已设置：%d~%d%%\n", lower, upper);
        pCharacteristic->setValue(String("HUM_OK:") + lower + "," + upper);
        pCharacteristic->notify();
      } else {
        pCharacteristic->setValue("HUM_FORMAT_ERR");
        pCharacteristic->notify();
      }
    }
    // 4. 设备昵称指令
    else if (rxValue.indexOf("NICK:") == 0) {
      const char* nickPrefix = "NICK:";
      int prefixLen = strlen(nickPrefix);
      // 2. 获取 UTF-8 编码的中文昵称字节流（rxValue 是接收到的 UTF-8 字节数组）
      const uint8_t* nickBytes = (uint8_t*)(rxValue.c_str() + prefixLen);
      int nickByteLen = rxValue.length() - prefixLen;

      // 3. 校验昵称长度（不超过存储数组-1，留结尾\0）
      if (nickByteLen > 0 && nickByteLen < 31) {
        // 4. 拷贝 UTF-8 字节到设备配置（直接存 UTF-8，不转码）
        memset(deviceConfig.device_nickname, 0, 32); // 清空原有数据
        memcpy(deviceConfig.device_nickname, nickBytes, nickByteLen);
        deviceConfig.device_nickname[nickByteLen] = '\0'; // 加字符串结束符
      // String nickname = rxValue.substring(5);
      // if (nickname.length() > 0) {
      //   nickname.toCharArray(deviceConfig.device_nickname, sizeof(deviceConfig.device_nickname));
        saveConfigToFlash();
        
        Serial.printf("设备昵称已设置：%s\n", deviceConfig.device_nickname);
        pCharacteristic->setValue("NICK_OK");
        pCharacteristic->notify();
      } else {
        pCharacteristic->setValue("NICK_FAIL");
        pCharacteristic->notify();
      }
    }
    // 5. 设备位置指令
    else if (rxValue.indexOf("LOC:") == 0) {
      const char* locPrefix = "LOC:";
      int prefixLen = strlen(locPrefix);
      // 2. 获取 UTF-8 编码的中文昵称字节流（rxValue 是接收到的 UTF-8 字节数组）
      const uint8_t* locBytes = (uint8_t*)(rxValue.c_str() + prefixLen);
      int locByteLen = rxValue.length() - prefixLen;

      // 3. 校验昵称长度（不超过存储数组-1，留结尾\0）
      if (locByteLen > 0 && locByteLen < 31) {
        // 4. 拷贝 UTF-8 字节到设备配置（直接存 UTF-8，不转码）
        memset(deviceConfig.device_location, 0, 32); // 清空原有数据
        memcpy(deviceConfig.device_location, locBytes, locByteLen);
        deviceConfig.device_location[locByteLen] = '\0'; // 加字符串结束符
      // String location = rxValue.substring(4);
      // if (location.length() > 0) {
      //   location.toCharArray(deviceConfig.device_location, sizeof(deviceConfig.device_location));
        saveConfigToFlash();
        
        Serial.printf("设备位置已设置：%s\n", deviceConfig.device_location);
        pCharacteristic->setValue("LOC_OK");
        pCharacteristic->notify();
      } else {
        pCharacteristic->setValue("LOC_FAIL");
        pCharacteristic->notify();
      }
    }
    // 6. MQTT配置指令
    else if (rxValue.indexOf("MQTT:") == 0) {
      int commaIndex = rxValue.indexOf(',');
      if (commaIndex != -1) {
        String server = rxValue.substring(5, commaIndex);
        uint16_t port = rxValue.substring(commaIndex + 1).toInt();
        
        server.toCharArray(deviceConfig.mqtt_server, sizeof(deviceConfig.mqtt_server));
        deviceConfig.mqtt_port = port;
        saveConfigToFlash();
        
        client.setServer(deviceConfig.mqtt_server, deviceConfig.mqtt_port);
        Serial.printf("MQTT已设置：%s:%d\n", deviceConfig.mqtt_server, deviceConfig.mqtt_port);
        
        pCharacteristic->setValue("MQTT_OK");
        pCharacteristic->notify();
      } else {
        pCharacteristic->setValue("MQTT_FAIL");
        pCharacteristic->notify();
      }
    }
    // 7. 刷新频率指令
    else if (rxValue.indexOf("REFRESH:") == 0) {
      unsigned long interval = rxValue.substring(8).toInt();
      if (interval >= 500 && interval <= 30000) {
        deviceConfig.read_interval = interval;
        saveConfigToFlash();
        
        Serial.printf("刷新频率已设置：%dms\n", interval);
        pCharacteristic->setValue("REFRESH_OK");
        pCharacteristic->notify();
      } else {
        pCharacteristic->setValue("REFRESH_FAIL");
        pCharacteristic->notify();
      }
    }
    // 8. 熄屏时间指令
    else if (rxValue.indexOf("SCREEN:") == 0) {
      unsigned long offTime = rxValue.substring(7).toInt();
      deviceConfig.screen_off_time = offTime;
      saveConfigToFlash();
      
      Serial.printf("熄屏时间已设置：%dms（0=常亮）\n", offTime);
      pCharacteristic->setValue("SCREEN_OK");
      pCharacteristic->notify();
    }
    // 9. 清除配置指令
    else if (rxValue == "CLEAR") {
      clearAllConfig();
      pCharacteristic->setValue("CLEAR_OK");
      pCharacteristic->notify();
      Serial.println("所有配置已清除");
    }
    // 10. 获取配置指令
    else if (rxValue == "GET_CONFIG") {
      String configStr = String("TEMP:") + deviceConfig.TEMP_Lower + "," + deviceConfig.TEMP_Upper + "|";
      configStr += "HUM:" + String(deviceConfig.HUM_Lower) + "," + deviceConfig.HUM_Upper + "|";
      configStr += "NICK:" + String(deviceConfig.device_nickname) + "|";
      configStr += "LOC:" + String(deviceConfig.device_location) + "|";
      configStr += "MQTT:" + String(deviceConfig.mqtt_server) + "," + deviceConfig.mqtt_port + "|";
      configStr += "REFRESH:" + String(deviceConfig.read_interval) + "|";
      configStr += "SCREEN:" + String(deviceConfig.screen_off_time);
      
      pCharacteristic->setValue(configStr);
      pCharacteristic->notify();
      Serial.println("已发送当前配置");
    }
    // 未知指令
    else {
      pCharacteristic->setValue("UNKNOWN_CMD");
      pCharacteristic->notify();
    }
  }
};
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
void loop() {
  portENTER_CRITICAL(&coreMux);
  memcpy((void*)&currentTime, (void*)&syncTimeInfo, sizeof(struct tm));
  timeIsSynced = isTimeSynced;
  mqttConnected = isServerConnected;
  portEXIT_CRITICAL(&coreMux);

  // 熄屏逻辑
  TouchState = digitalRead(TouchPin);
  if (deviceConfig.screen_off_time > 0) {
    if (millis() - screenOnTimer > deviceConfig.screen_off_time && screenIsOn) {
      screenIsOn = false;
      u8g2.clearBuffer();
      u8g2.sendBuffer();
      Serial.println("屏幕已休眠");
    }else if(TouchState == LOW)  {
      delay(200);
      TouchState = digitalRead(TouchPin);
      if(TouchState == HIGH){
        screenIsOn = true;
        screenOnTimer = millis();
        Serial.println("屏幕已唤醒");
      }
    }
  }else{
    screenIsOn = true;
  }

  // 修改：刷新频率从配置读取
  if (millis() - ReadTimer > deviceConfig.read_interval) {
    ReadTimer = millis();
    
    if (readAHT10(temperature, humidity)) {
      temp_result = round(temperature*10)/10.0-10;
      hum_result = round(humidity*10)/10.0;
      
      int temp = round(temp_result*10);
      temp_decimal = temp %10;
      temp_integer = temp /10;

      int hum = round(hum_result*10);
      hum_decimal = hum %10;
      hum_integer = hum /10;
      
      Serial.print("【");
      Serial.print(deviceConfig.device_nickname);
      Serial.print(" - ");
      Serial.print(deviceConfig.device_location);
      Serial.print("】");
      
      Serial.print("时间: ");
      if(timeIsSynced){
        char timeStr[20];
        strftime(timeStr, sizeof(timeStr), "%Y-%m-%d %H:%M:%S", &currentTime);
        Serial.print(timeStr);
      }else{
        Serial.print(millis());
      }
      Serial.print("\t温度: ");
      Serial.print(temp_result);
      Serial.print("°C\t湿度: ");
      Serial.print(hum_result);
      Serial.println("%");

      if (deviceConnected && bleRunning) {
        String dataStr = String(temp_result) + "," + String(humidity, 1);
        pCharacteristic->setValue(dataStr.c_str());
        pCharacteristic->notify();
      }

      if (client.connected() && timeIsSynced) {
        if (millis() - lastMsg > deviceConfig.read_interval) { 
          lastMsg = millis();
          char timeStr[20];
          strftime(timeStr, sizeof(timeStr), "%Y-%m-%d %H:%M:%S", &currentTime);
          
          String payload = "{";
            payload += "\"time\":\"" + String(timeStr) + "\",";
            payload += "\"UUID\":\"" + String(SERVICE_UUID) + "\",";
            payload += "\"Nickname\":\"" + String(deviceConfig.device_nickname) + "\",";
            payload += "\"Location\":\"" + String(deviceConfig.device_location) + "\",";
            payload += "\"temp\":" + String(temp_result) + ",";
            payload += "\"humi\":" + String(humidity, 1);
            payload += "}";
          client.publish("home/sensor/th", payload.c_str());
          Serial.print("MQTT 数据已发送: ");
          Serial.println(payload);
        }
      }
    }
  }

  if (millis() - oledUpdateTimer > OLED_UPDATE_INTERVAL) {
    oledUpdateTimer = millis();
    page_style_2();
  }

  // WiFi连接逻辑（保留原代码，仅修改配置读取源）
  if (shouldConnectWiFi) {
    shouldConnectWiFi = false;
    isConnecting = true;
    wifiTimer = millis();
    
    Serial.println("开始连接 WiFi...");
    WiFi.begin(pendingSSID.c_str(), pendingPASS.c_str());
  }

  if (isConnecting) {
    if (WiFi.status() == WL_CONNECTED) {
      isConnecting = false;
      Serial.println("WiFi 连接成功!");
      
      pendingSSID.toCharArray(deviceConfig.ssid, sizeof(deviceConfig.ssid));
      pendingPASS.toCharArray(deviceConfig.password, sizeof(deviceConfig.password));
      deviceConfig.hasConfig = 0xAA;
      saveConfigToFlash();

      if(bleRunning && deviceConnected){
        pCharacteristic->setValue("WIFI_OK");
        pCharacteristic->notify();
      }

      portENTER_CRITICAL(&coreMux);
      timeSyncFlag = true;
      portEXIT_CRITICAL(&coreMux);
    } 
    else if (millis() - wifiTimer > WiFi_Timeout_INTERVAL) {
      Serial.println("WiFi 连接超时失败");
      startBLE();
      isConnecting = false;
      WiFi.disconnect();
      
      if(bleRunning && deviceConnected){
        pCharacteristic->setValue("WIFI_FAIL");
        pCharacteristic->notify();
      }
    }
  } else if(WiFi.status() != WL_CONNECTED){
    if (!bleRunning) {
      startBLE();
    }
  } else if (WiFi.status() == WL_CONNECTED && isServerConnected) {
    // if (bleRunning && !deviceConnected) {
    //   stopBLE();
    // }
  }

  // MQTT状态检查（保留原代码）
  if (WiFi.status() == WL_CONNECTED) {
    client.loop();
    
    if (!client.connected()) {
      if(millis() - mqttReconnectTimer > MQTT_RECONNECT_INTERVAL){
        mqttReconnectTimer = millis();
        portENTER_CRITICAL(&coreMux);
        mqttReconnectFlag = true;
        portEXIT_CRITICAL(&coreMux);
      }
      if (!bleRunning) {
        startBLE();
      }
    }
    if(client.connected()){
      isServerConnected = true;
      // if (bleRunning && !deviceConnected) {
      //   stopBLE();
      // }
    }
  } else {
    isServerConnected = false;
  }
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

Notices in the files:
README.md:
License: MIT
